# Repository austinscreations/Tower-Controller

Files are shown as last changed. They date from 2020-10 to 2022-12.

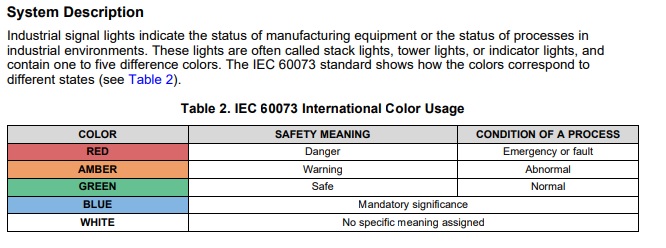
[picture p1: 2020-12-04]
tower light clasification.jpg

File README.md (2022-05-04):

# Tower Controller
# formerly mini-notification-tower

I've recently found good sellers for lower cost industrial towers, while I'll still 3d print my own 180 degree tower light and share files should someone want to build one, I've now designed a semi-universal controller for controlling analog 12-24v tower lights

New code can be found here: [Github](https://github.com/austinscreations/OXRS-AC-TowerController-ESP8266-FW) <br>
Load up a bin file in wifi or ethernet mode and provision the device using the admin UI: [Github](https://github.com/OXRS-IO/OXRS-IO-AdminUI-WEB-APP) <br>
Compatable with the (http://oxrs.io) system

As someone who has a home office and a workshop in the garage I wanted an easy way to have notifications whereever I am.
traditional 5 layer led notification lights are large and pricey.
I set out to make a smaller alternative solution. with 3d printing I made a 180 degree light, with the help of a 3d printed mold I was able to use epoxy resin and tints to create the lenses.

-

Red - flashing - immediate issue (such as a fire alarm or CO alarm)

Red - machine error (cnc or 3d printer)

Yellow - flashing - machine error / require attention (such as a 3d printer filament sensor or 3d print ends)

Yellow - equipement On - temperature related (3d printer active (hot end or heat bed) or soldering iron on)

Green - equipment on but idle (say 3d printer or soldering iron is on but not running a job

Blue - notifications (with the help of an I2C lcd I'm able to show messages

White - tied to my doorbell (one to my office door and front house door)

-

Version 1 used 5mm leds in a 3d printed insert - mosfets controlelr wired to 5v and arduino nano. the arduino nano was linked to an rf433 reciever for the doorbell.

Version 2 will include a PCB for a Wemos d1 mini and SMD leds, and I want to try to make a 360 degree model as well.
          
RF433 will be offloaded to a esp-01 to build a seprate gateway for my home assitant installation.

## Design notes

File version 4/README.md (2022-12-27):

this latest version include builtin ethernet support, POE support and runs on esp32

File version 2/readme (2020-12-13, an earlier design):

Version 2 

This version has the tower assembly using 5730 LEd's for lighting and a spot on the pcb for a wemos D1 mini.

***this version is larger than the v1 so taht both the 180 degree and 360 degree assebbilies can be the same size.***

Requires 12v power to run - diode proetcting 5v regualtor when programming via usb

will be updated as I create the PCB files, code and 3d housings will be made and adjusted once I order parts for assembly and testing.

2020-12-12
updated control board pcb in version 2 stacking edition
added intial 3d model photo of teh 3d printable model that will be used to assemble the lights

2020-12-04
added photos of the pcb designs of each version
added cost breakdown in main version 22 folder for each version. doesn't include 3d printed parts / power supply - using ebay canada as source

2020-12-03:
Created new files. there are different assemblies. 

180 version = has a single led panel with wemos d1 mini - giving ~180 degree ilumination

360 stacking = used a control board and led boards - using brass stand offs to conenct each baord. there are solder jumpers which are to be used to route the signal
for the ws2811s chip that controls the led mosfets. the depending on led color you need 82 ohm or 39 ohm 2010 1 watt resistors (text on pcb). 
each baord will allow you to program 3 segment animations on the led baord. 3d printed parts with 45 degree angles nad chrome paint can be used to redirect light.

360 version = uses 4 straight led panels to connect to a control board via 90 degree headers. uses ws2811s chip to control LED mosfets

Boards are currently untested and don't have 3d assembly files, working on multiple projects and home to do a mass ebay order to fill parts on these projects to keep my costs down.

Hope to expore the option of a POE powered and ethernet controlled tower

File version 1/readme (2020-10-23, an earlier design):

Readme for version 1

This version was created as I was testing a concept. I had intended to add an esp-01 to the arduino nano.
I wasn't able to have reliable communication through the esp-01 so version 2 will use a wemos d1 mini at it's core.

As this was a test for me and only uses an RF433mhz reciever to control the white led I wont be posting any code.

version 1 was hand soldered and 5mm led sat within a 3d printed insert. The lenses were made with a 3d printed mold filed with epoxy resin 
i used cheap dollar store resin as a test and didn't want to use my high quality stuff. and used resin tint for the colors.

The LEDS match the lens color - I found this gives the best results as using the white leds on the color produced a washed out color.

normal state of the lcd is to state time and temperature.

COMPUTER ASSEMBLY - 
holder - this was a holder i made that slides over my dual monitor mount post, it has a sleep and reset button along with lcd display spot.

sleep was used for when i'd go to bed as the arduino nano has control over the door bell sound it will play the sound every so often until i wake up and reset it.
   good for me as I'm partly deaf. it would also turn off the screen so that my room would be dark for sleeping
reset is used to reset the screen notification and intern reset a color on the tower if needed.

led panel is the panel used to insert 5mm leds and solder them together with resisters.

tower light cover is the back cover for the assembly, i glued mine in place, passed etehrnet cable thru the hole for the led wiring

tower light is the main tower assembly.

LENS - 

lens mold is parts a and b, they were alligned and hot glue at the seam. mann mold release 200 was used to prevent the resin from sticking.

lens shaper - i would allow the lens to mostly cure and still be flexible (warning teh resin wil lstill be warm in this state - i'd remove it from teh mold and place it within the shaper
this ensured that the lens was easy to remove from the mold and any moving it did coming out of teh mold gave it a chance to cure in the correct shape. found this gave me the best results
and with the use of 5 minute epoxy gave me chance to make lenses really quickly.

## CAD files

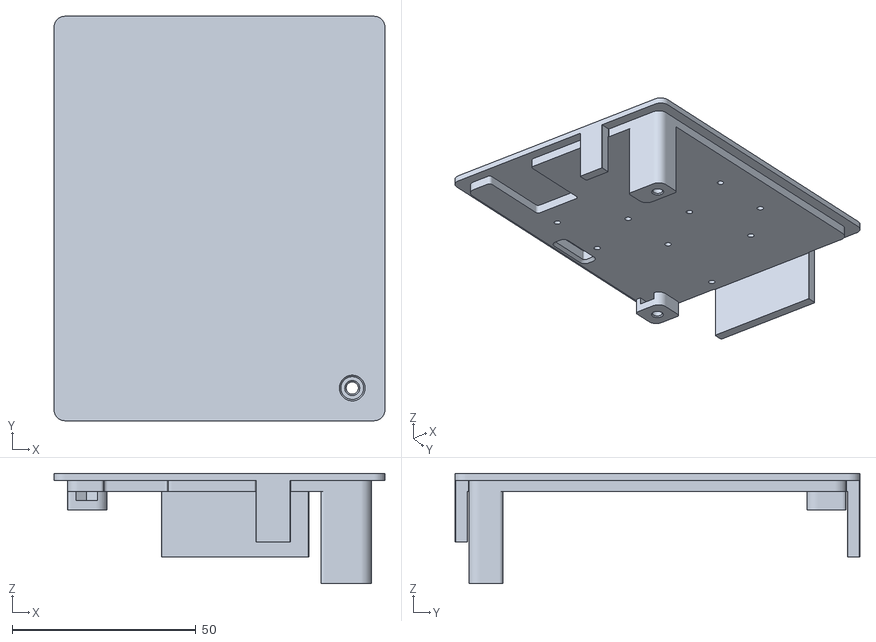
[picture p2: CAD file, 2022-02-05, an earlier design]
version 3/3d printable case/main lid.stl
90.0 x 110.0 x 30.0

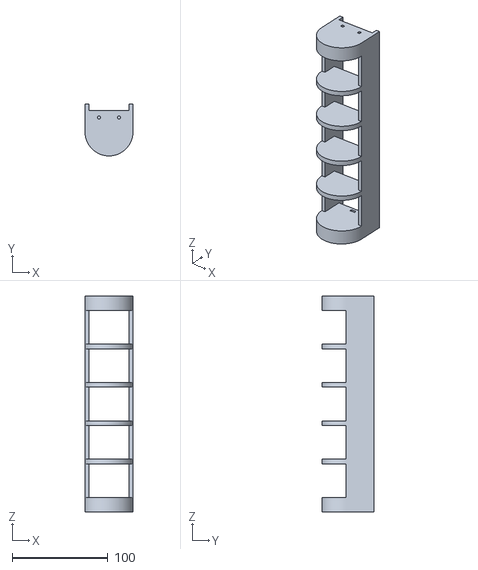
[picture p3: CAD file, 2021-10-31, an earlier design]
version 3/CAD/main body.stl
50.0 x 54.0 x 225.0

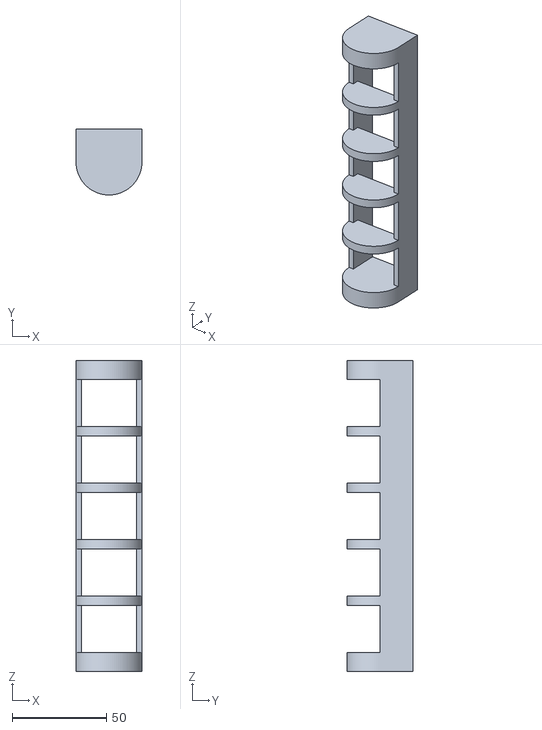
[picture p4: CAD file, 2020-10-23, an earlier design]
version 1/computer assembly/computer tower light.stl
35.0 x 35.0 x 165.0

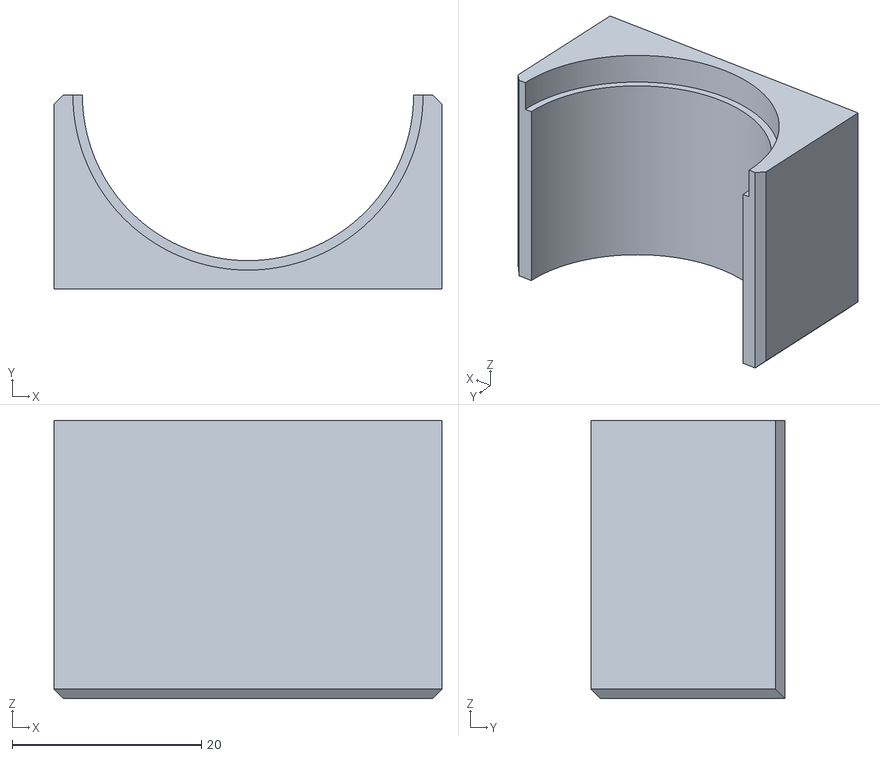
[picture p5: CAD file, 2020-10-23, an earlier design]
version 1/lens/lens mold 2.stl
41.0 x 20.5 x 29.4

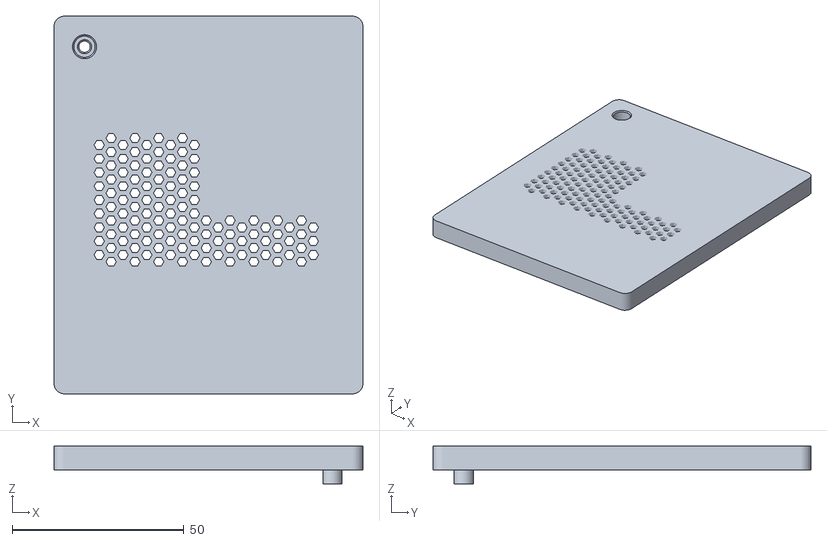
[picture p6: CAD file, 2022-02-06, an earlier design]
version 3/3d printable case/sensor lid.stl
90.0 x 110.0 x 11.0

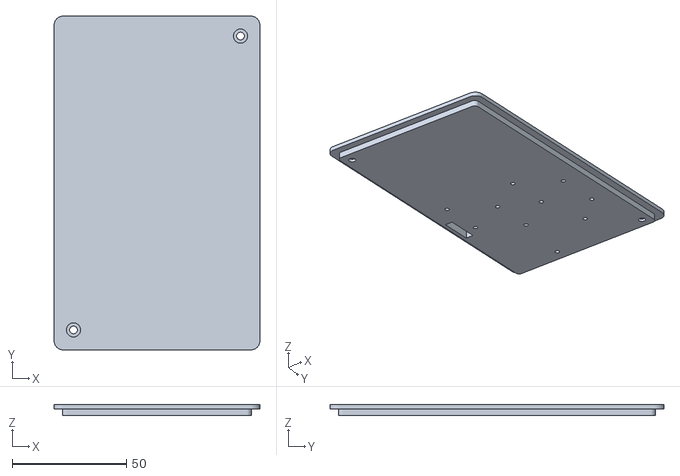
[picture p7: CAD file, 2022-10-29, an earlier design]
version 3/3d printable case/wall mount case/wall case lid v1.stl
90.0 x 146.0 x 5.00

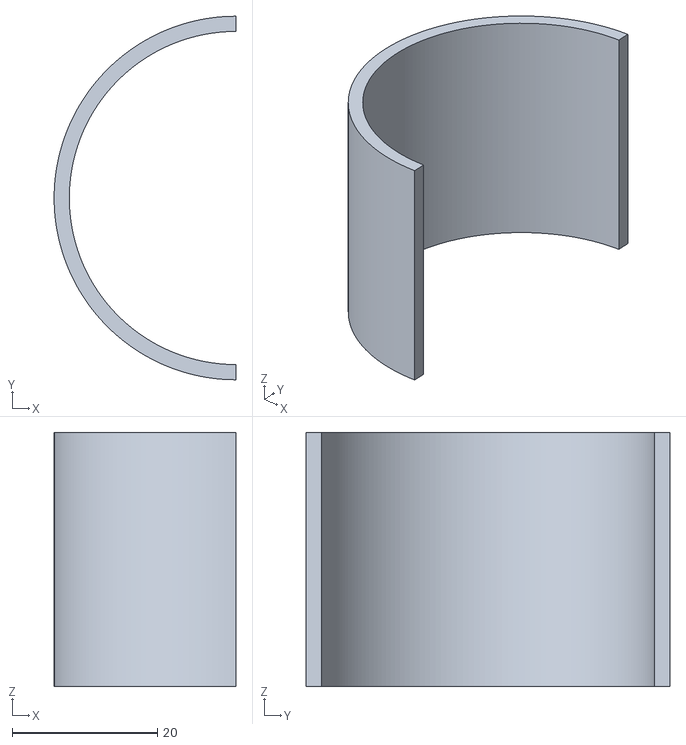
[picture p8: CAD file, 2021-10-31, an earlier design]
version 3/CAD/lens.stl
25.0 x 50.1 x 35.0

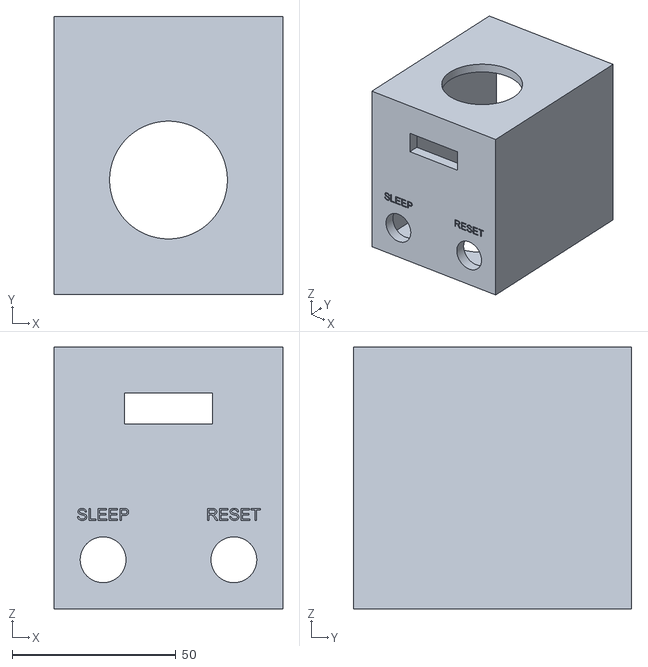
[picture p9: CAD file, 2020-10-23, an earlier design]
version 1/computer assembly/computer holder.stl
70.0 x 85.0 x 80.0

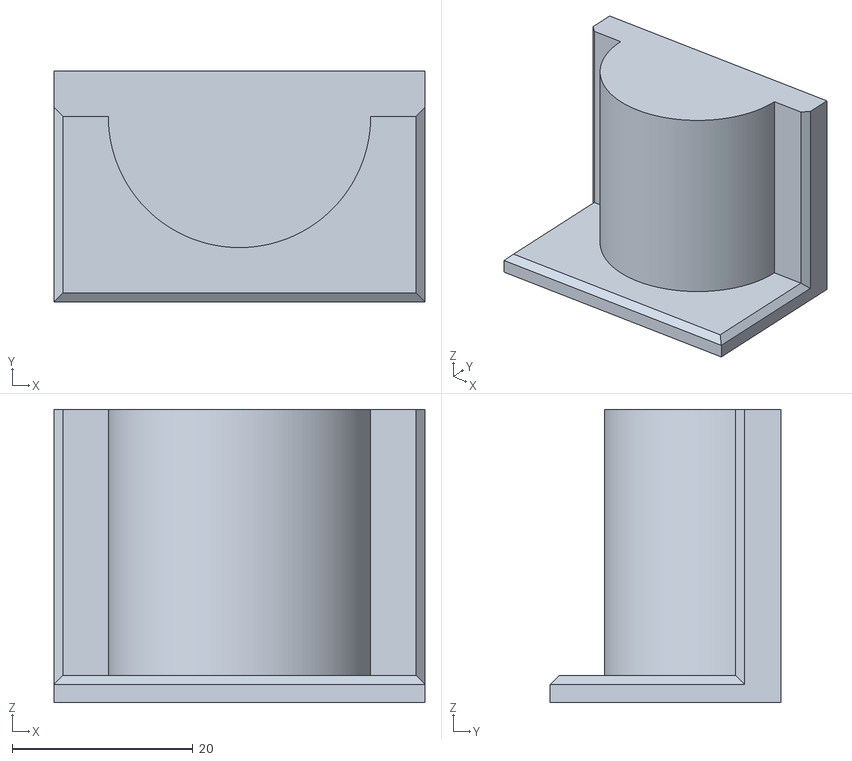
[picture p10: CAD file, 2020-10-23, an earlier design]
version 1/lens/lens mold 1.stl
41.0 x 25.5 x 32.4

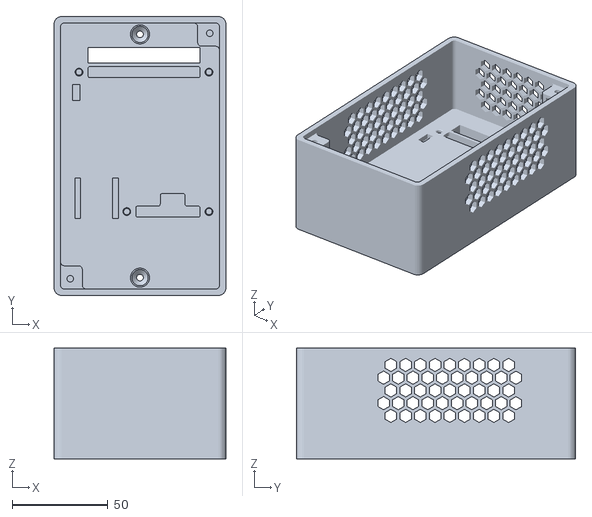
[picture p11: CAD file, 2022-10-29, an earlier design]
version 3/3d printable case/wall mount case/wall case v1.stl
90.0 x 146.0 x 58.0

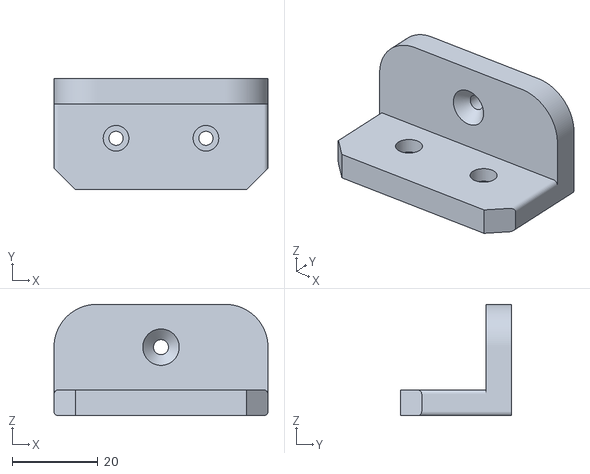
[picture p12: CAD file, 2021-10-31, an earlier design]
version 3/CAD/wall mount.stl
50.0 x 26.0 x 26.0

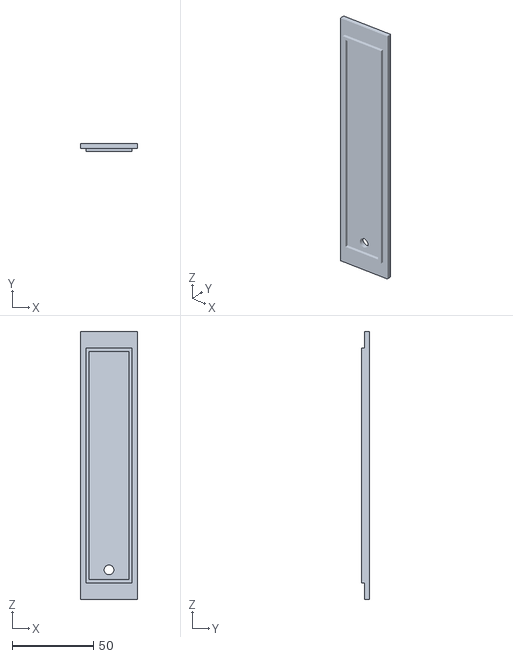
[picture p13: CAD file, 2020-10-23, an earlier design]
version 1/computer assembly/computer tower light cover.stl
35.0 x 5.00 x 165.0

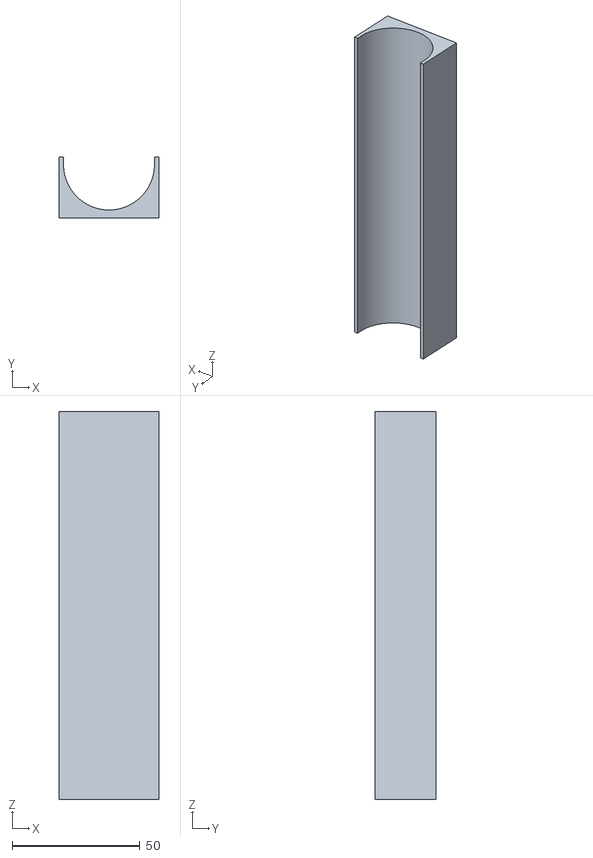
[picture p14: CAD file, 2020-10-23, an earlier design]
version 1/lens/Resin lens shaper.stl
39.0 x 24.0 x 152.0

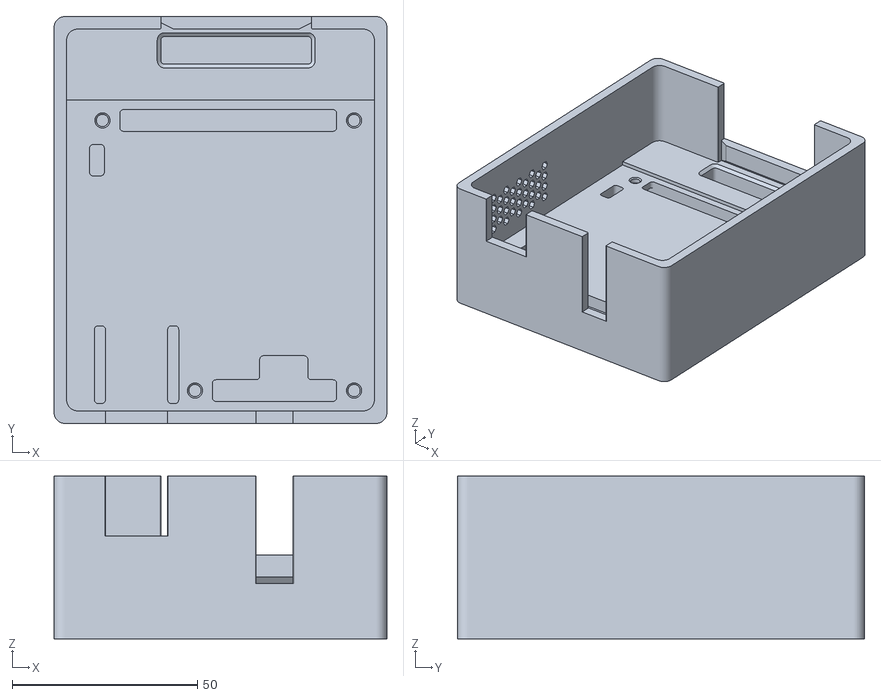
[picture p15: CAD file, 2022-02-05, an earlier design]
version 3/3d printable case/case.stl
90.0 x 110.0 x 44.0

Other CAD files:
version 3/CAD/mold rest.stl
version 1/computer assembly/computer led panel.stl
version 3/CAD/back panel.stl
version 3/CAD/tower light.step
version 3/CAD/mold a.stl
version 3/CAD/mold b.stl

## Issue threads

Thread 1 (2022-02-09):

ScreenMode is missing in 1.0.2

aspork42, 2022-02-09:
References to ScreenMode no longer appear in 1.0.2 (as compared with 0.9)

austinscreations, 2022-02-09:
updated nodered flow and screenmode code moved to OXRS sensor library

Closed 2022-02-09.

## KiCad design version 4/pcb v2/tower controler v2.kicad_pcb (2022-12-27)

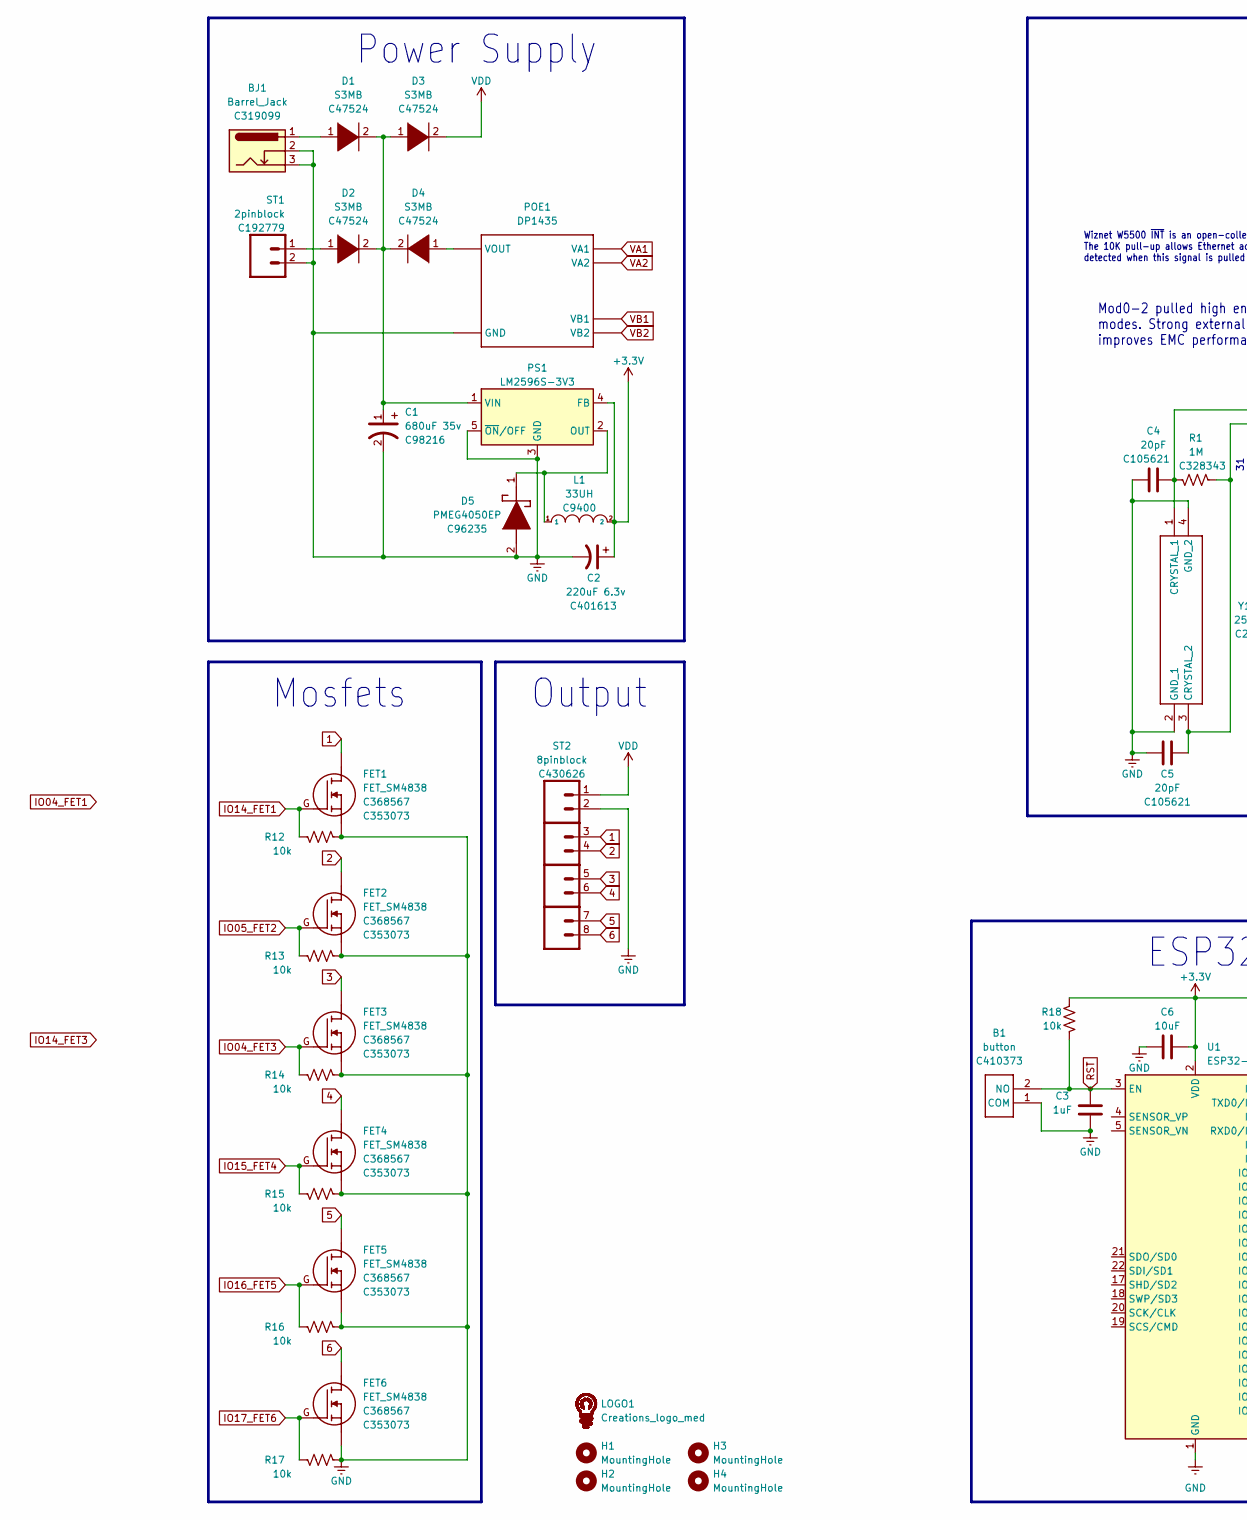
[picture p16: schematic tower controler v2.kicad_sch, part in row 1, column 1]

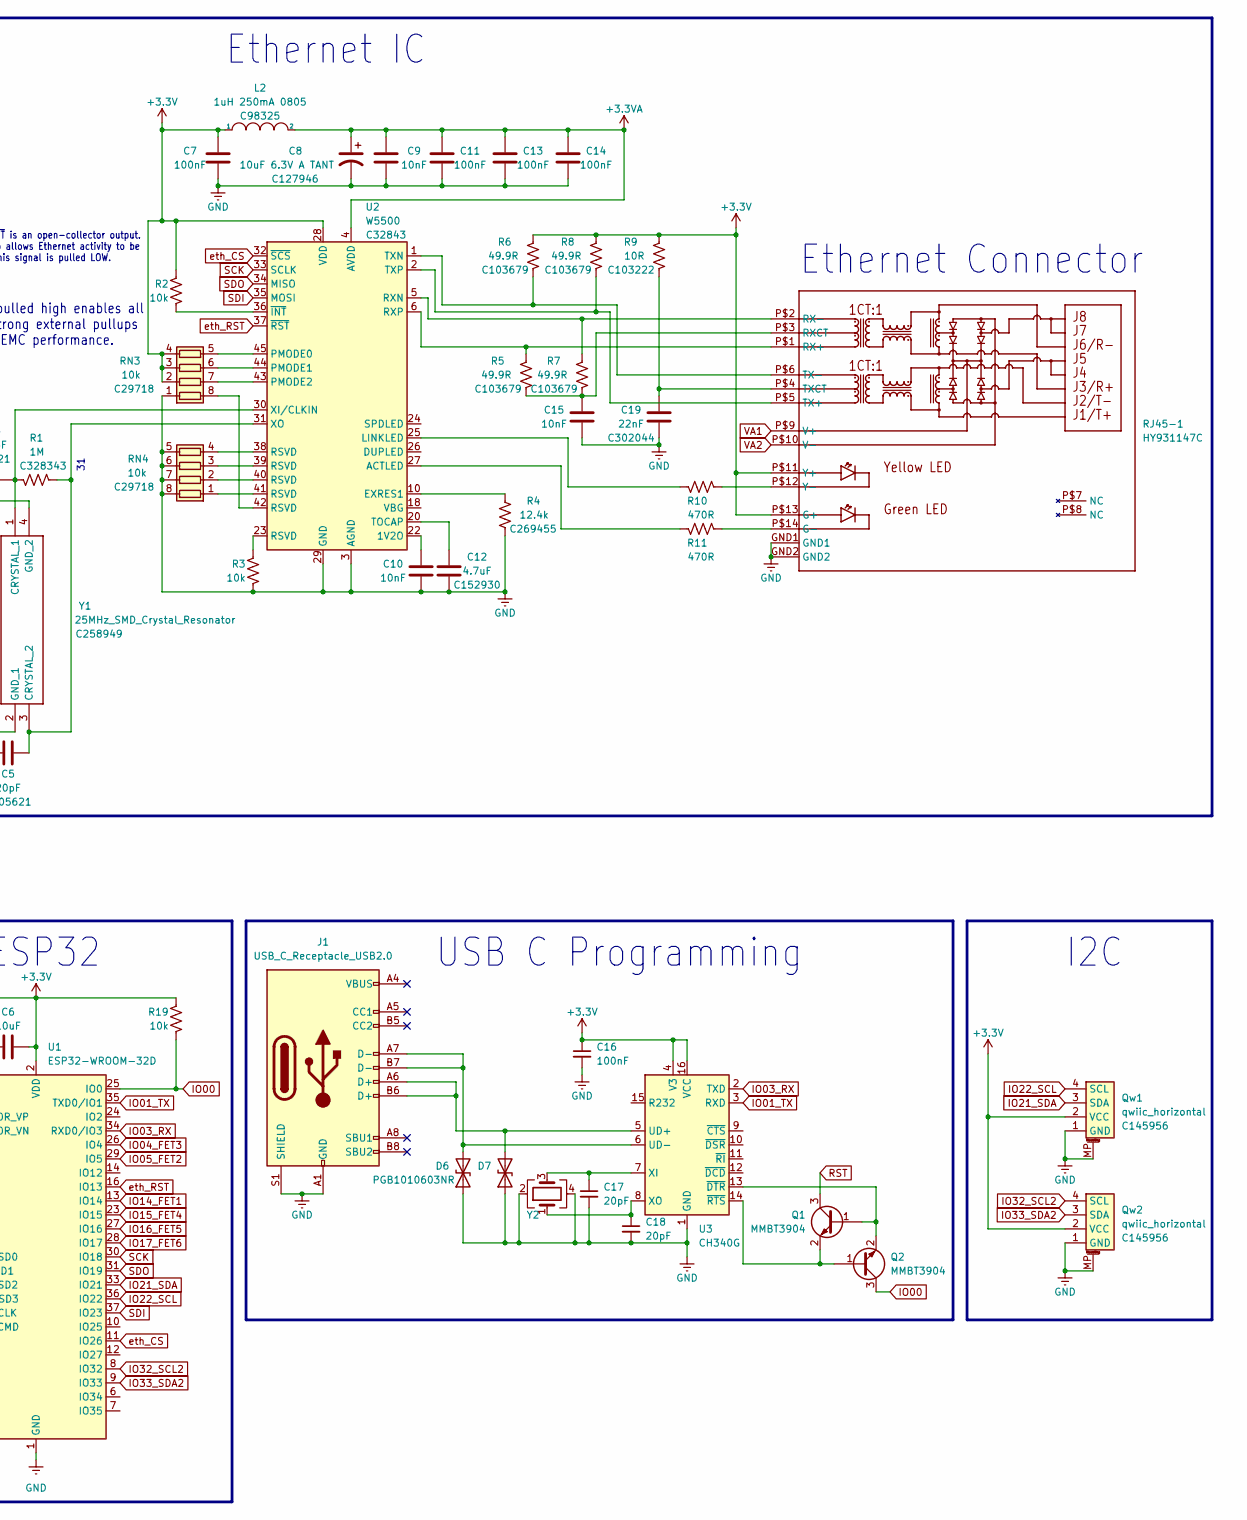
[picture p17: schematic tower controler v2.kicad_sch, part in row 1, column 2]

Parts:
B1: button; part # C410373
BJ1: Barrel_Jack; Barrel Jack; part # C319099
C1: 680uF 35v; large capacitor 12.5d 13.5h; part # C98216
C2: 220uF 6.3v; CP_Elec_8x6.2; part # C401613
C3: 1uF; C_0603_1608Metric
C4, C5: 20pF; C_0603_1608Metric; part # C105621
C6: 10uF; C_0603_1608Metric
C7, C11, C13, C14, C16: 100nF; C_0603_1608Metric
C8: 10uF 6.3V A TANT; CP_EIA-3216-18_Kemet-A; part # C127946
C9, C10, C15: 10nF; C_0603_1608Metric
C12: 4.7uF; C_0603_1608Metric; part # C152930
C17, C18: 20pF; C_0603_1608Metric
C19: 22nF; C_0603_1608Metric; part # C302044
D1, D2, D3, D4: S3MB; D_SMB; part # C47524
D5: PMEG4050EP; PMEG3050EP; part # C96235
D6, D7: PGB1010603NR; D_0603_1608Metric
FET1, FET2, FET3, FET4, FET5, FET6: FET_SM4838; FET SM4838; part # C368567
H1, H2, H3, H4: MountingHole; MountingHole_3.2mm_M3
J1: USB_C_Receptacle_USB2.0; USB_C_Receptacle_HRO_TYPE-C-31-M-12
L1: 33UH; 12x12x8 inductor; part # C9400
L2: 1uH 250mA 0805; L_0805_2012Metric; part # C98325
LOGO1: Creations_logo_med; Creations logo med
POE1: DP1435
PS1: LM2596S-3V3; LM2596S
Q1, Q2: MMBT3904; SOT-23
Qw1, Qw2: qwiic_horizontal; qwiic horizontal; part # C145956
R1: 1M; R_0603_1608Metric; part # C328343
R2, R3, R12, R13, R14, R15, R16, R17, R18, R19: 10k; R_0603_1608Metric
R4: 12.4k; R_0603_1608Metric; part # C269455
R5, R6, R7, R8: 49.9R; R_0603_1608Metric; part # C103679
R9: 10R; R_0603_1608Metric; part # C103222
R10, R11: 470R; R_0603_1608Metric
RJ45-1: HY931147C
RN3, RN4: 10k; R_Array_Convex_4x0603; part # C29718
ST1: 2pinblock; part # C192779
ST2: 8pinblock; part # C430626
U1: ESP32-WROOM-32D; ESP32-WROOM-32
U2: W5500; LQFP-48_7x7mm_P0.5mm; part # C32843
U3: CH340G; SOIC-16_3.9x9.9mm_P1.27mm
Y1: 25MHz_SMD_Crystal_Resonator; part # C258949
Y2: Crystal_GND23; Crystal_SMD_3225-4Pin_3.2x2.5mm

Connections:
1: FET1.D, ST2.3
2: FET2.D, ST2.4
3: FET3.D, ST2.5
4: FET4.D, ST2.6
5: FET5.D, ST2.7
6: FET6.D, ST2.8
+3.3VA: C8.1, C9.2, C11.2, C13.2, C14.2, L2.2, U2.4 (AVDD), U2.8 (AVDD), U2.11 (AVDD), U2.15 (AVDD), U2.17 (AVDD), U2.21 (AVDD)
+3V3: C2.1, C6.2, C7.2, C16.1, L1.2, L2.1, PS1.4 (FB), Qw1.2 (VCC), Qw2.2 (VCC), R2.2, R6.2, R8.2, R9.2, R18.2, R19.2, RJ45-1.P$11 (Y+), RJ45-1.P$13 (G+), RN3.2 (R2.1), RN3.3 (R3.1), RN3.4 (R4.1), U1.2 (VDD), U2.28 (VDD), U3.4 (V3), U3.16 (VCC)
GNDREF: B1.1 (COM), BJ1.2, BJ1.3, C1.2, C2.2, C3.1, C4.1, C5.1, C6.1, C7.1, C8.2, C9.1, C10.1, C11.1, C12.1, C13.1, C14.1, C15.1, C16.2, C17.2, C18.2, C19.1, D5.2 (A), D6.1 (A1), D7.1 (A1), FET1.S, FET2.S, FET3.S, FET4.S, FET5.S, FET6.S, J1.A1 (GND), J1.A12 (GND), J1.B1 (GND), J1.B12 (GND), J1.S1 (SHIELD), POE1.GND, PS1.3 (GND), PS1.5 (~ON/OFF), Qw1.1 (GND), Qw1.MP, Qw2.1 (GND), Qw2.MP, R3.1, R4.1, R12.1, R13.1, R14.1, R15.1, R16.1, R17.1, RJ45-1.GND1, RJ45-1.GND2, RN3.1 (R1.1), RN4.5 (R4.2), RN4.6 (R3.2), RN4.7 (R2.2), RN4.8 (R1.2), ST1.2, ST2.2, U1.1 (GND), U1.15 (GND), U1.38 (GND), U1.39 (GND), U2.3 (AGND), U2.9 (AGND), U2.14 (AGND), U2.16 (AGND), U2.19 (AGND), U2.29 (GND), U2.48 (AGND), U3.1 (GND), Y1.2 (GND_1), Y1.4 (GND_2), Y2.2, Y2.4
IO00: Q2.3 (C), R19.1, U1.25 (IO0)
IO01_TX: U1.35 (TXD0/IO1), U3.3 (RXD)
IO03_RX: U1.34 (RXD0/IO3), U3.2 (TXD)
IO04_FET3: FET3.G, R14.2, U1.26 (IO4)
IO05_FET2: FET2.G, R13.2, U1.29 (IO5)
IO14_FET1: FET1.G, R12.2, U1.13 (IO14)
IO15_FET4: FET4.G, R15.2, U1.23 (IO15)
IO16_FET5: FET5.G, R16.2, U1.27 (IO16)
IO17_FET6: FET6.G, R17.2, U1.28 (IO17)
IO21_SDA: Qw1.3 (SDA), U1.33 (IO21)
IO22_SCL: Qw1.4 (SCL), U1.36 (IO22)
IO32_SCL2: Qw2.4 (SCL), U1.8 (IO32)
IO33_SDA2: Qw2.3 (SDA), U1.9 (IO33)
unnamed: BJ1.1, D1.1 (K)
unnamed: C1.1, D1.2 (A), D2.2 (A), D3.1 (K), D4.2 (A), PS1.1 (VIN)
unnamed: C4.2, R1.1, U2.30 (XI/CLKIN), Y1.1 (CRYSTAL_1)
unnamed: C5.2, R1.2, U2.31 (XO), Y1.3 (CRYSTAL_2)
unnamed: C10.2, U2.22 (1V2O)
unnamed: C12.2, U2.20 (TOCAP)
unnamed: C15.2, R5.1, R7.1, RJ45-1.P$3 (RXCT)
unnamed: C17.1, U3.7 (XI), Y2.3
unnamed: C18.1, U3.8 (XO), Y2.1
unnamed: C19.2, R9.1, RJ45-1.P$4 (TXCT)
unnamed: D2.1 (K), ST1.1
unnamed: D4.1 (K), POE1.VOUT
unnamed: D5.1 (K), L1.1, PS1.2 (OUT)
unnamed: D6.2 (A2), J1.A7 (D-), J1.B7 (D-), U3.6 (UD-)
unnamed: D7.2 (A2), J1.A6 (D+), J1.B6 (D+), U3.5 (UD+)
unnamed: Q1.1 (B), Q2.2 (E), U3.13 (~DTR)
unnamed: Q1.2 (E), Q2.1 (B), U3.14 (~RTS)
unnamed: R2.1, U2.36 (~INT)
unnamed: R3.2, U2.23 (RSVD)
unnamed: R4.2, U2.10 (EXRES1)
unnamed: R5.2, RJ45-1.P$1 (RX+), U2.6 (RXP)
unnamed: R6.1, RJ45-1.P$6 (TX-), U2.1 (TXN)
unnamed: R7.2, RJ45-1.P$2 (RX-), U2.5 (RXN)
unnamed: R8.1, RJ45-1.P$5 (TX+), U2.2 (TXP)
unnamed: R10.1, RJ45-1.P$12 (Y-)
unnamed: R10.2, U2.25 (LINKLED)
unnamed: R11.1, RJ45-1.P$14 (G-)
unnamed: R11.2, U2.27 (ACTLED)
unnamed: RN3.5 (R4.2), U2.45 (PMODE0)
unnamed: RN3.6 (R3.2), U2.44 (PMODE1)
unnamed: RN3.7 (R2.2), U2.43 (PMODE2)
unnamed: RN3.8 (R1.2), U2.42 (RSVD)
unnamed: RN4.1 (R1.1), U2.41 (RSVD)
unnamed: RN4.2 (R2.1), U2.40 (RSVD)
unnamed: RN4.3 (R3.1), U2.39 (RSVD)
unnamed: RN4.4 (R4.1), U2.38 (RSVD)
RST: B1.2 (NO), C3.2, Q1.3 (C), R18.1, U1.3 (EN)
SCK: U1.30 (IO18), U2.33 (SCLK)
SDI: U1.37 (IO23), U2.35 (MOSI)
SDO: U1.31 (IO19), U2.34 (MISO)
VA1: POE1.VA1, RJ45-1.P$9 (V+)
VA2: POE1.VA2, RJ45-1.P$10 (V-)
VB1: POE1.VB1
VB2: POE1.VB2
VDD: D3.2 (A), ST2.1
eth_CS: U1.11 (IO26), U2.32 (~SCS)
eth_RST: U1.16 (IO13), U2.37 (~RST)

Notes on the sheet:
Ethernet Connector
Ethernet IC
USB C Programming
ESP32
Power Supply
Mod0-2 pulled high enables all modes. Strong external pullups improves EMC performance.
Output
Mosfets
I2C
Wiznet W5500 ~{INT} is an open-collector output. The 10K pull-up allows Ethernet activity to be detected when this signal is pulled LOW.

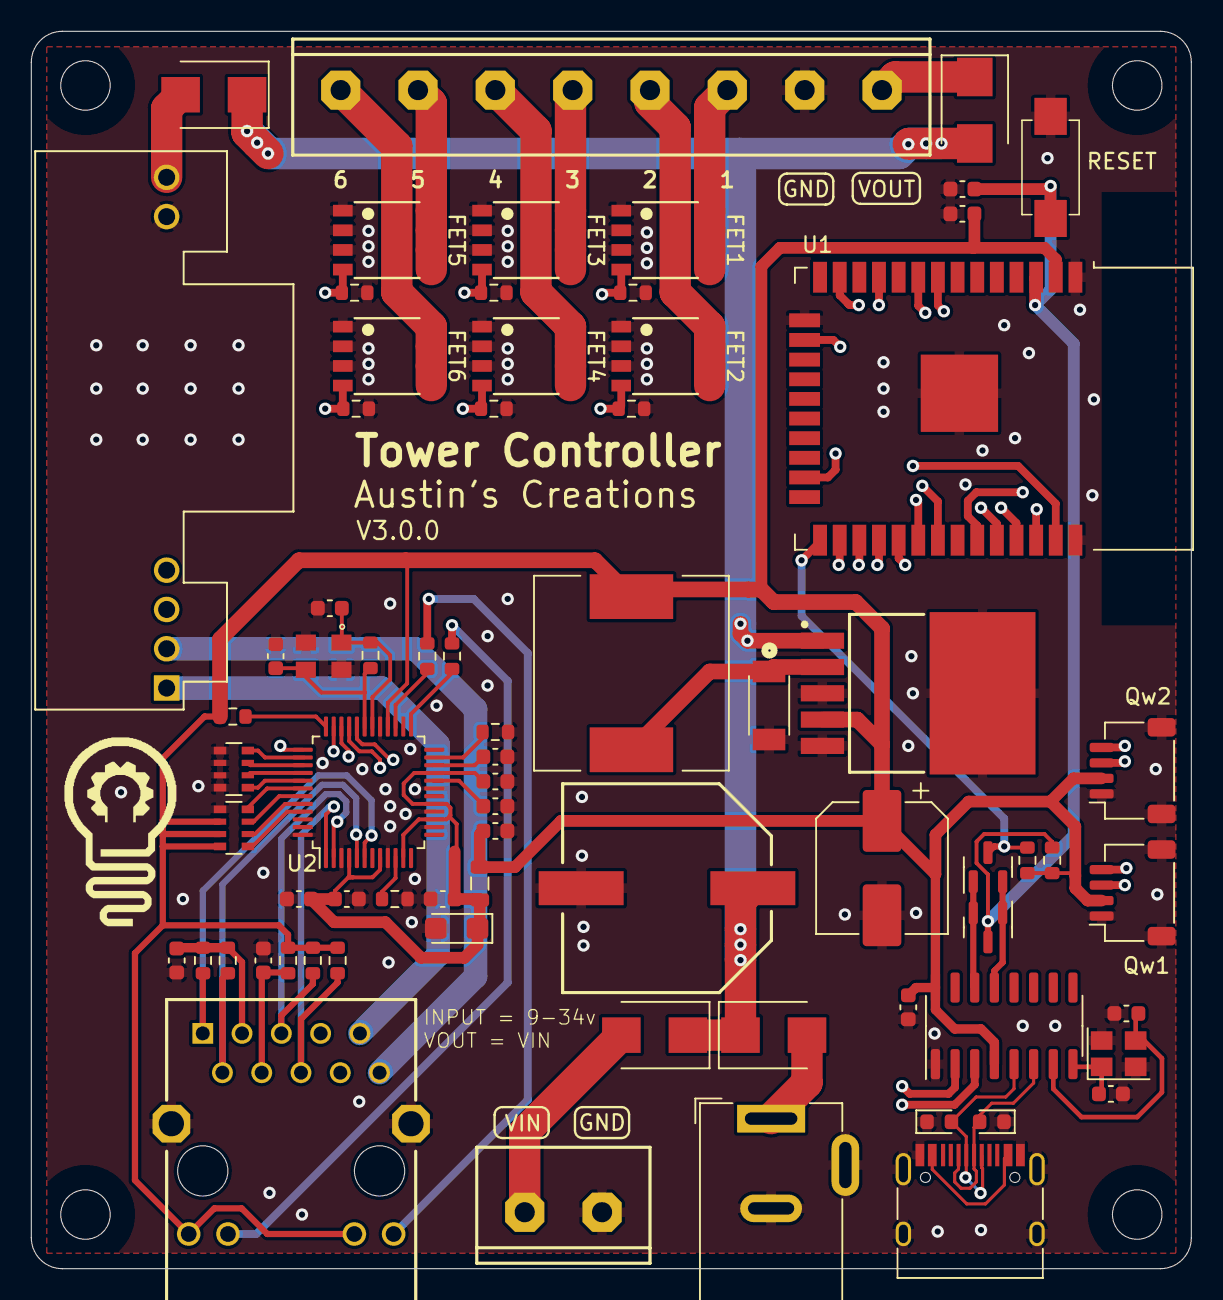
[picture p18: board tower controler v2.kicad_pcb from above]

Board: 4 copper layers, 75.0 x 80.0 mm, 77 parts (0 on the bottom side), 67 nets.

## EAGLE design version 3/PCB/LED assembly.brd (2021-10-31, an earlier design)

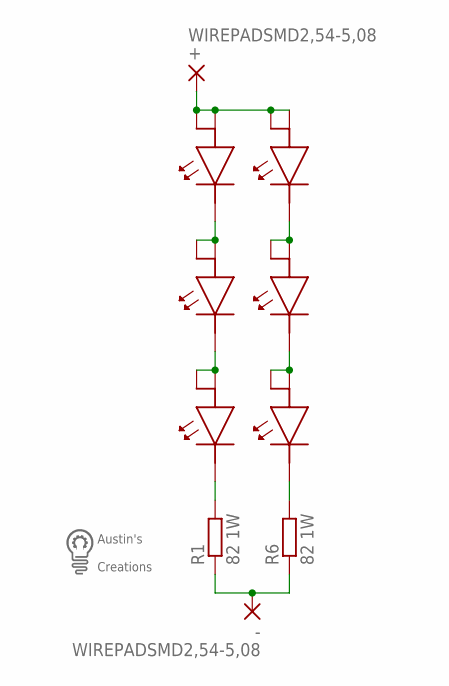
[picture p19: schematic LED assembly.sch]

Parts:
+: WIREPADSMD2,54-5,08; SMD2,54-5,08
-: WIREPADSMD2,54-5,08; SMD2,54-5,08
R1, R6: 82 1W; R2010
U$1: LOGOMED
U$6, U$7, U$8, U$23, U$24, U$25: 5730LED

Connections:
N: U$6.P$2, U$7.P$1, U$7.P$3
unnamed: -.1, R1.1, R6.1
unnamed: U$7.P$2, U$8.P$1, U$8.P$3
unnamed: R1.2, U$8.P$2
unnamed: U$23.P$2, U$24.P$1, U$24.P$3
unnamed: U$24.P$2, U$25.P$1, U$25.P$3
unnamed: R6.2, U$25.P$2
VIN: +.1, U$6.P$1, U$6.P$3, U$23.P$1, U$23.P$3

Board: 2 copper layers, 11 parts (0 on the bottom side), 8 nets, no tracks yet.

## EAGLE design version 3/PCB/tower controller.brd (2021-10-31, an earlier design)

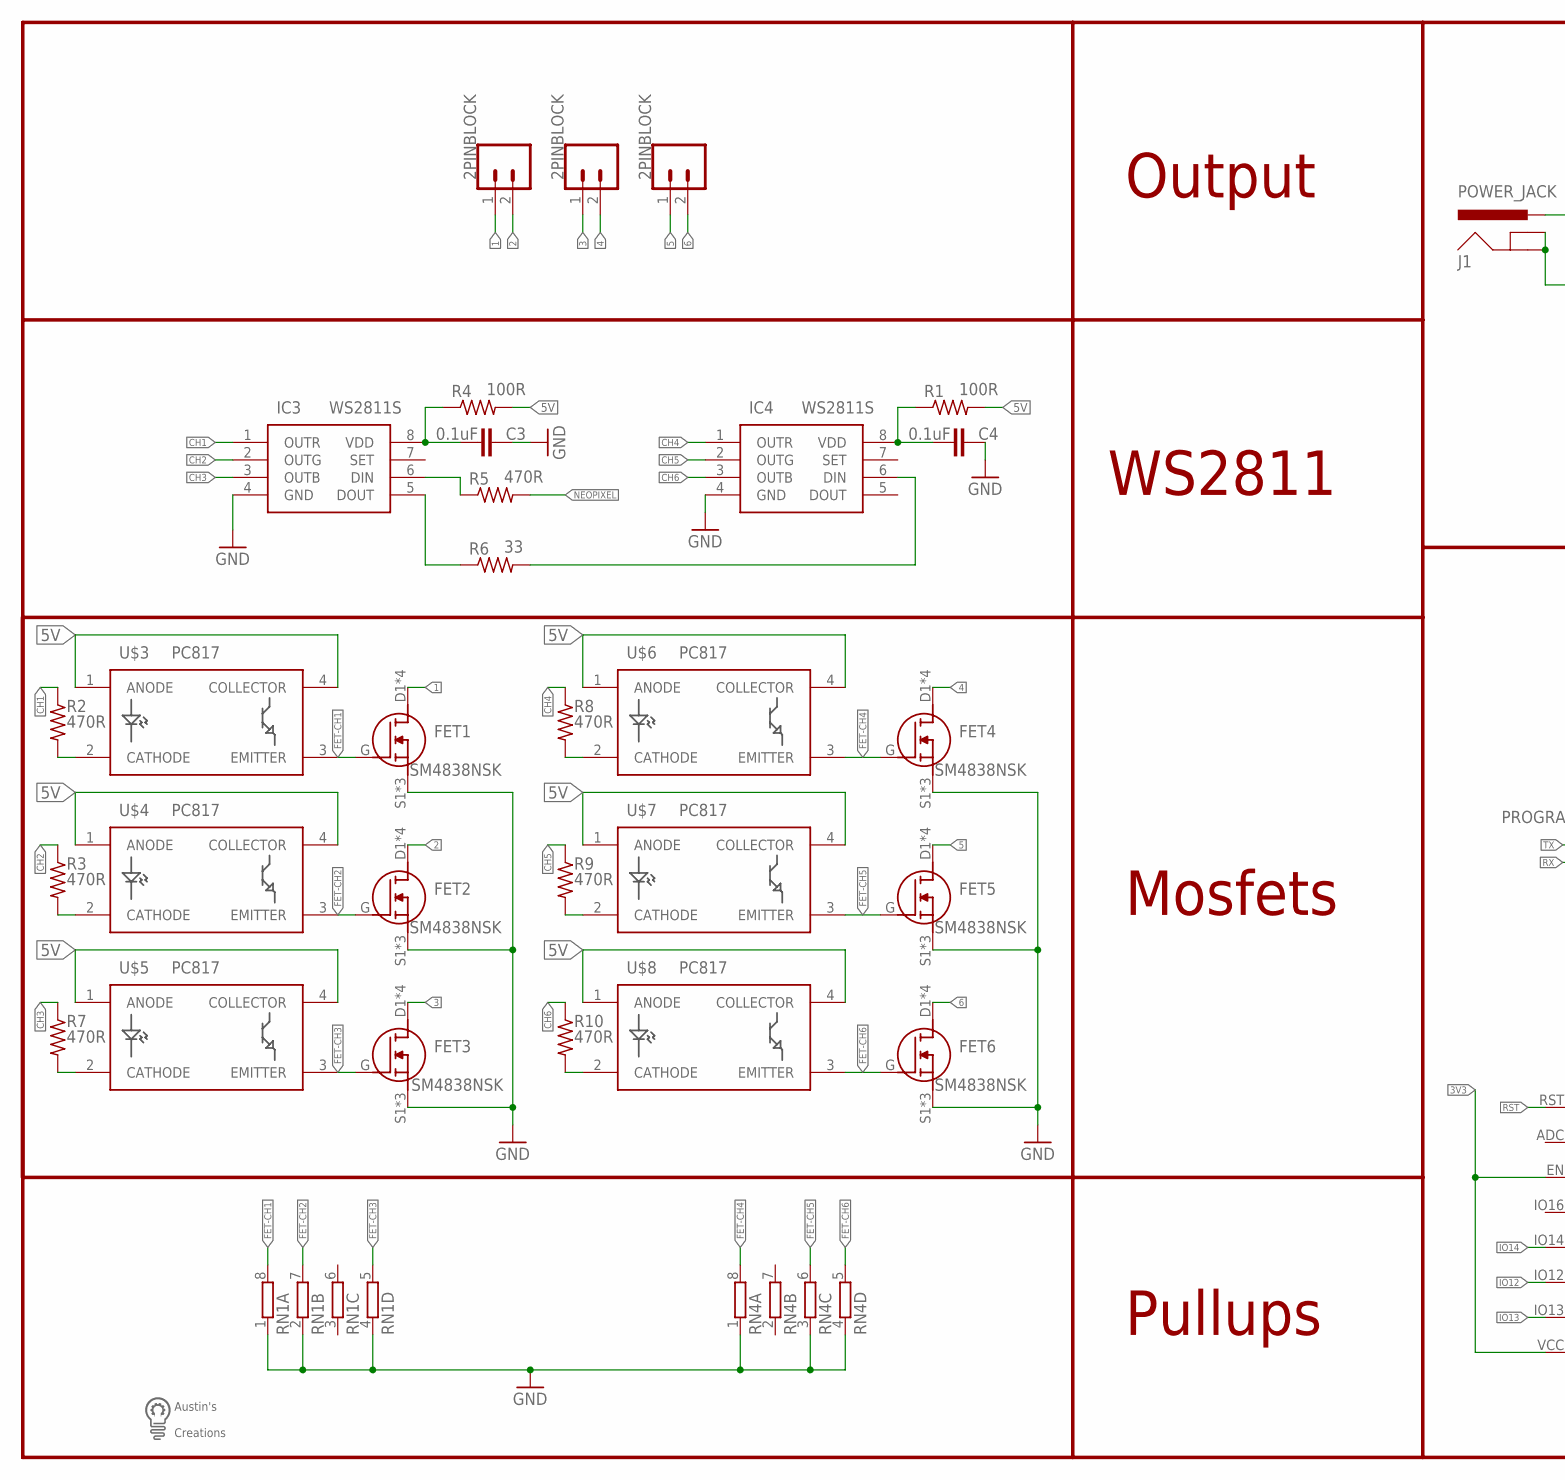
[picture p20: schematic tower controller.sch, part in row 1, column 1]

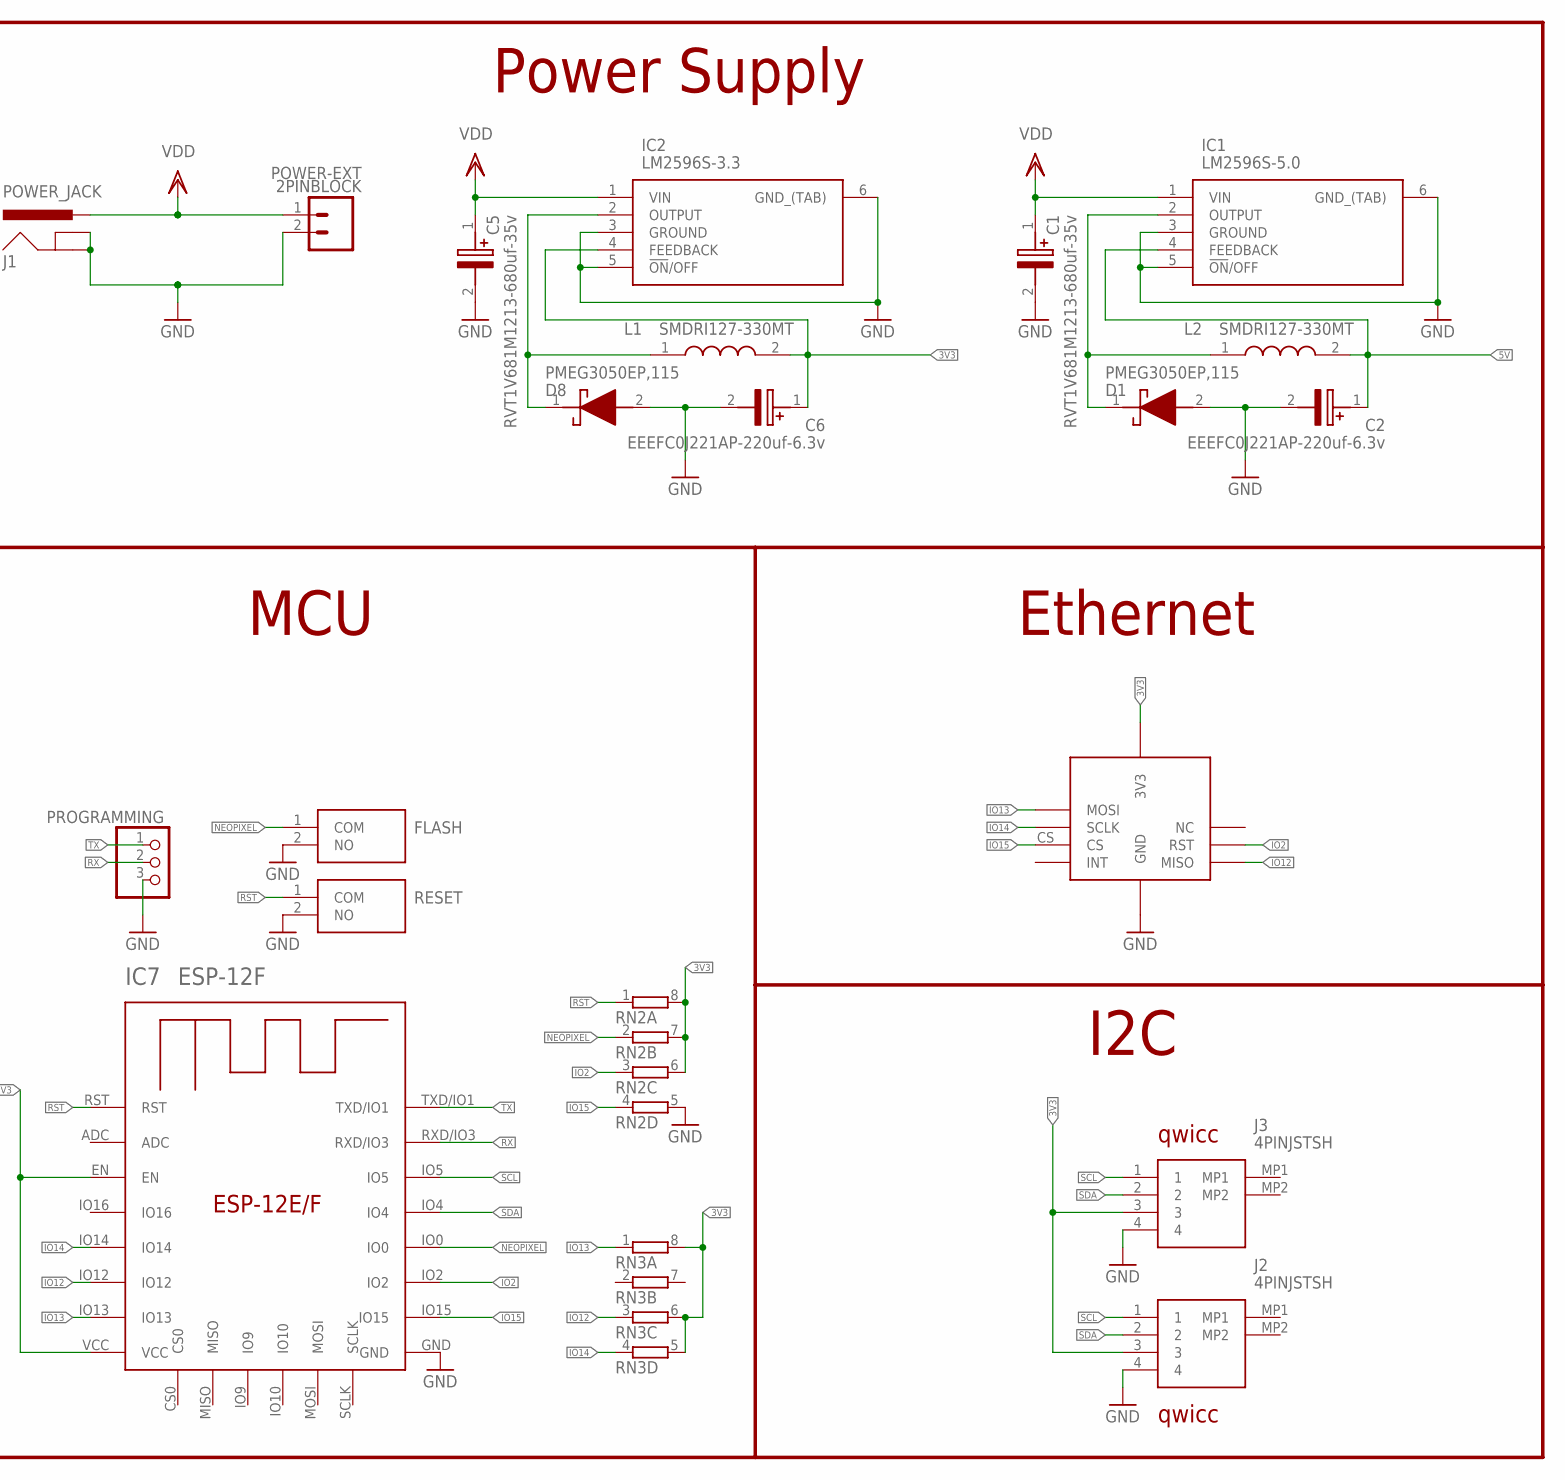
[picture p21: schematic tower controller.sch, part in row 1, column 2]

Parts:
C1, C5: RVT1V681M1213-680uf-35v; CAPAE1350X1400N
C2, C6: EEEFC0J221AP-220uf-6.3v; CAPAE830X650N
C3, C4: 0.1uF; C0603
D1, D8: PMEG3050EP,115; PMEG3050EP115
FET1, FET2, FET3, FET4, FET5, FET6: SM4838NSK
FLASH: PTS636_SM25F_SMTR_LFS; PTS636SM25FSMTRLFS
GND, GND10, GND11: 2PINBLOCK; SCREWTERMINAL-5MM-2
IC1: LM2596S-5.0; TO170P1435X465-6N
IC2: LM2596S-3.3; TO170P1435X465-6N
IC3, IC4: WS2811S; SOIC127P600X175-8N
IC7: ESP-12F; ESP-12E
J1: POWER_JACK; POWER_JACK_PTH
J2, J3: 4PINJSTSH; 665104131822
L1, L2: SMDRI127-330MT; INDPM120120X800N
POWER-EXT: 2PINBLOCK; SCREWTERMINAL-5MM-2
PROGRAMMING: PINHD-1X3; 1X03
R1, R4: 100R; R0603
R2, R3, R5, R7, R8, R9, R10: 470R; R0603
R6: 33; R0603
RESET: PTS636_SM25F_SMTR_LFS; PTS636SM25FSMTRLFS
RN1, RN2, RN3, RN4: 4R-N0603-ARC; 0603-ARC
U$1: W5500MODULE
U$2: LOGOMED
U$3, U$4, U$5, U$6, U$7, U$8: PC817; SOP254P960X420-4N

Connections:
1: FET1.D1 (D), FET1.D2 (D), FET1.D3 (D), FET1.D4 (D), GND.1
2: FET2.D1 (D), FET2.D2 (D), FET2.D3 (D), FET2.D4 (D), GND.2
3: FET3.D1 (D), FET3.D2 (D), FET3.D3 (D), FET3.D4 (D), GND10.1
3V3: C6.1 (+), IC2.4 (FEEDBACK), IC7.EN, IC7.VCC, J2.3, J3.3, L1.2, RN2.6 (2), RN2.7 (2), RN2.8 (2), RN3.5 (2), RN3.6 (2), RN3.8 (2), U$1.3V3_1 (3V3), U$1.3V3_2 (3V3)
4: FET4.D1 (D), FET4.D2 (D), FET4.D3 (D), FET4.D4 (D), GND10.2
5: FET5.D1 (D), FET5.D2 (D), FET5.D3 (D), FET5.D4 (D), GND11.1
5V: C2.1 (+), IC1.4 (FEEDBACK), L2.2, R1.2, R4.2, U$3.1 (ANODE), U$3.4 (COLLECTOR), U$4.1 (ANODE), U$4.4 (COLLECTOR), U$5.1 (ANODE), U$5.4 (COLLECTOR), U$6.1 (ANODE), U$6.4 (COLLECTOR), U$7.1 (ANODE), U$7.4 (COLLECTOR), U$8.1 (ANODE), U$8.4 (COLLECTOR)
6: FET6.D1 (D), FET6.D2 (D), FET6.D3 (D), FET6.D4 (D), GND11.2
CH1: IC3.1 (OUTR), R2.1
CH2: IC3.2 (OUTG), R3.1
CH3: IC3.3 (OUTB), R7.1
CH4: IC4.1 (OUTR), R8.1
CH5: IC4.2 (OUTG), R9.1
CH6: IC4.3 (OUTB), R10.1
FET-CH1: FET1.G, RN1.8 (2), U$3.3 (EMITTER)
FET-CH2: FET2.G, RN1.7 (2), U$4.3 (EMITTER)
FET-CH3: FET3.G, RN1.5 (2), U$5.3 (EMITTER)
FET-CH4: FET4.G, RN4.8 (2), U$6.3 (EMITTER)
FET-CH5: FET5.G, RN4.6 (2), U$7.3 (EMITTER)
FET-CH6: FET6.G, RN4.5 (2), U$8.3 (EMITTER)
GND: C1.2 (-), C2.2 (-), C3.1, C4.1, C5.2 (-), C6.2 (-), D1.2 (A), D8.2 (A), FET1.S1 (S), FET1.S2 (S), FET1.S3 (S), FET2.S1 (S), FET2.S2 (S), FET2.S3 (S), FET3.S1 (S), FET3.S2 (S), FET3.S3 (S), FET4.S1 (S), FET4.S2 (S), FET4.S3 (S), FET5.S1 (S), FET5.S2 (S), FET5.S3 (S), FET6.S1 (S), FET6.S2 (S), FET6.S3 (S), FLASH.2 (NO), IC1.3 (GROUND), IC1.5 (!ON!/OFF), IC1.6 (GND_(TAB)), IC2.3 (GROUND), IC2.5 (!ON!/OFF), IC2.6 (GND_(TAB)), IC3.4 (GND), IC4.4 (GND), IC7.GND, J1.GND, J1.GNDBREAK, J2.4, J3.4, POWER-EXT.2, PROGRAMMING.3, RESET.2 (NO), RN1.1, RN1.2 (1), RN1.4 (1), RN2.5 (2), RN4.1, RN4.3 (1), RN4.4 (1), U$1.GND1 (GND), U$1.GND2 (GND), U$1.GND3 (GND)
IO2: IC7.IO2, RN2.3 (1), U$1.RST
IO12: IC7.IO12, RN3.3 (1), U$1.MISO
IO13: IC7.IO13, RN3.1, U$1.MOSI
IO14: IC7.IO14, RN3.4 (1), U$1.SCLK
IO15: IC7.IO15, RN2.4 (1), U$1.CS
unnamed: D1.1 (K), IC1.2 (OUTPUT), L2.1
unnamed: C4.2, IC4.8 (VDD), R1.1
unnamed: IC4.6 (DIN), R6.2
unnamed: C3.2, IC3.8 (VDD), R4.1
unnamed: IC3.6 (DIN), R5.1
unnamed: IC3.5 (DOUT), R6.1
unnamed: R3.2, U$4.2 (CATHODE)
unnamed: R2.2, U$3.2 (CATHODE)
unnamed: R7.2, U$5.2 (CATHODE)
unnamed: R8.2, U$6.2 (CATHODE)
unnamed: R9.2, U$7.2 (CATHODE)
unnamed: R10.2, U$8.2 (CATHODE)
unnamed: D8.1 (K), IC2.2 (OUTPUT), L1.1
NEOPIXEL: FLASH.1 (COM), IC7.IO0, R5.2, RN2.2 (1)
RST: IC7.RST, RESET.1 (COM), RN2.1
RX: IC7.RXD/IO3, PROGRAMMING.2
SCL: IC7.IO5, J2.1, J3.1
SDA: IC7.IO4, J2.2, J3.2
TX: IC7.TXD/IO1, PROGRAMMING.1
VDD: C1.1 (+), C5.1 (+), IC1.1 (VIN), IC2.1 (VIN), J1.PWR, POWER-EXT.1

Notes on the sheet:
qwicc
MCU
Power Supply
Ethernet
I2C
WS2811
Mosfets
Output
Pullups

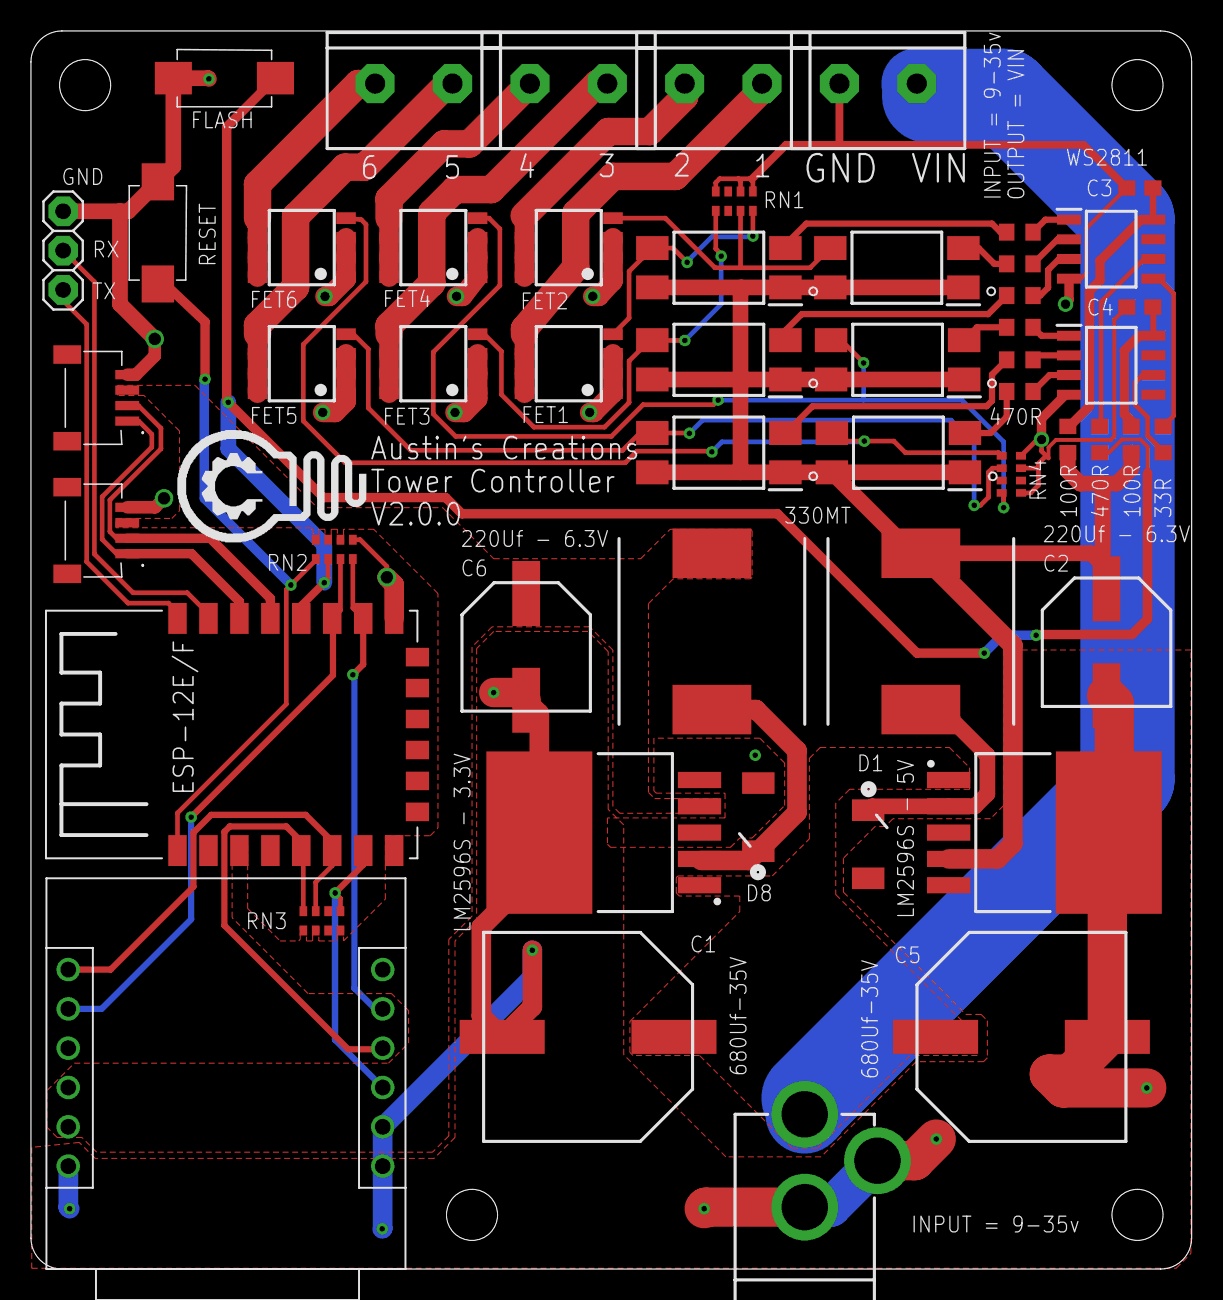
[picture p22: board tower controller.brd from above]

Board: 2 copper layers, 75.0 x 80.0 mm, 53 parts (0 on the bottom side), 46 nets.

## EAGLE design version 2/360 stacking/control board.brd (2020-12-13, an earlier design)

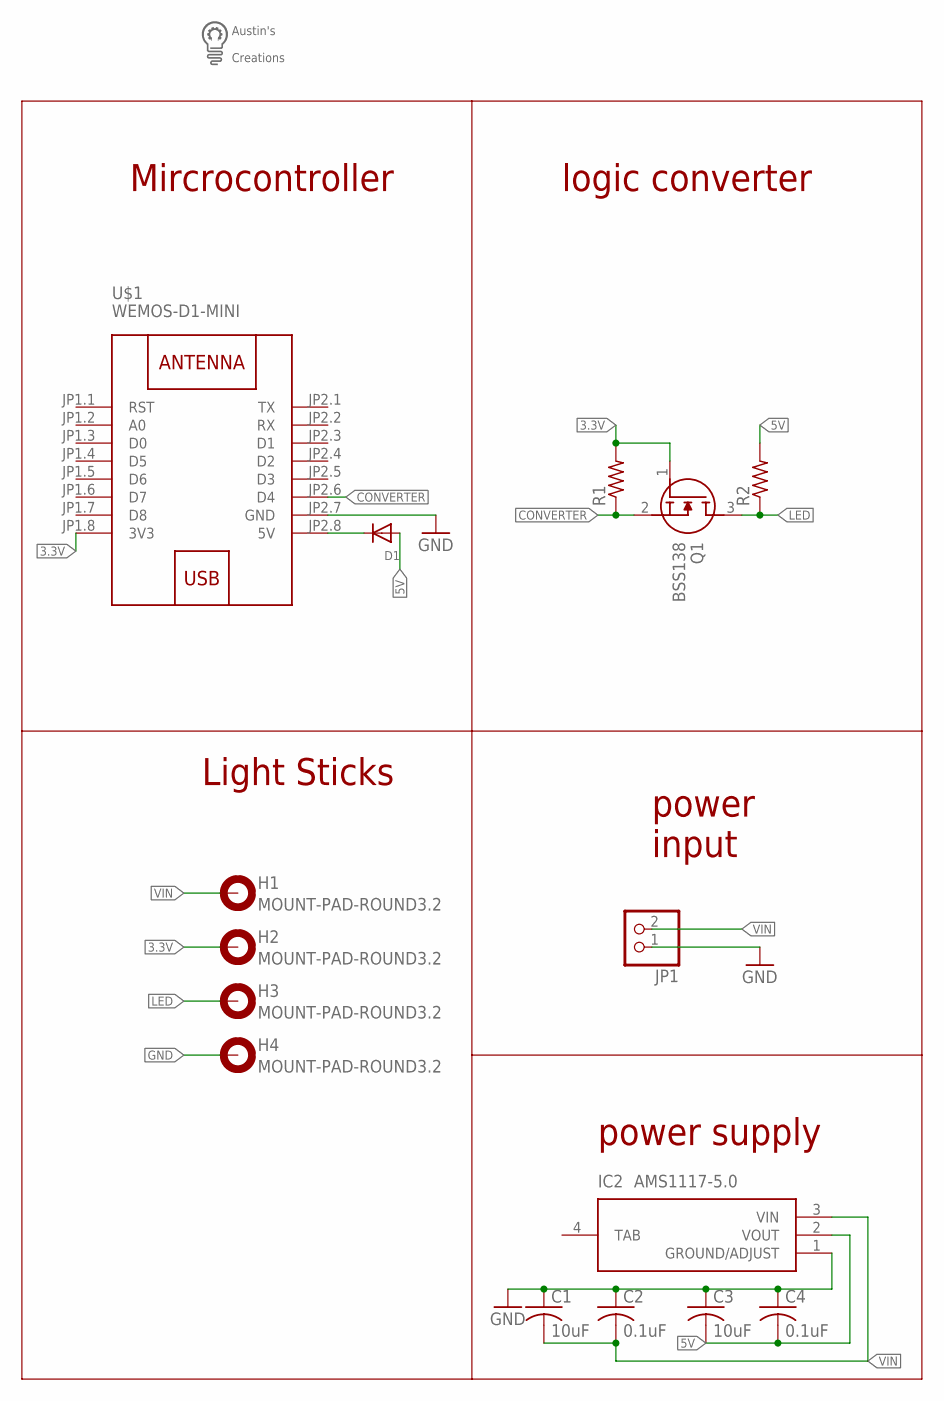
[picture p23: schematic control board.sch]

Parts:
C1, C3: 10uF; C0603
C2, C4: 0.1uF; C0603
D1: DIODESOD-123; SOD-123
H1, H2, H3, H4: MOUNT-PAD-ROUND3.2; 3,2-PAD
IC2: AMS1117-5.0; SOT229P700X180-4N
JP1: PINHD-1X2; 1X02
Q1: BSS138; SOT95P240X120-3N
R1, R2: R-US_R0603; R0603
U$1: WEMOS-D1-MINI
U$2: LOGO

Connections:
3.3V: H2.B3,2, Q1.1 (G), R1.2, U$1.JP1.8 (3V3)
5V: C3.2, C4.2, D1.A, IC2.2 (VOUT), R2.2
CONVERTER: Q1.2 (S), R1.1, U$1.JP2.6 (D4)
GND: C1.1, C2.1, C3.1, C4.1, H4.B3,2, IC2.1 (GROUND/ADJUST), JP1.1, U$1.JP2.7 (GND)
LED: H3.B3,2, Q1.3 (D), R2.1
unnamed: D1.C, U$1.JP2.8 (5V)
VIN: C1.2, C2.2, H1.B3,2, IC2.3 (VIN), JP1.2

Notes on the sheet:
Light Sticks
power supply
power input
Mircrocontroller
logic converter

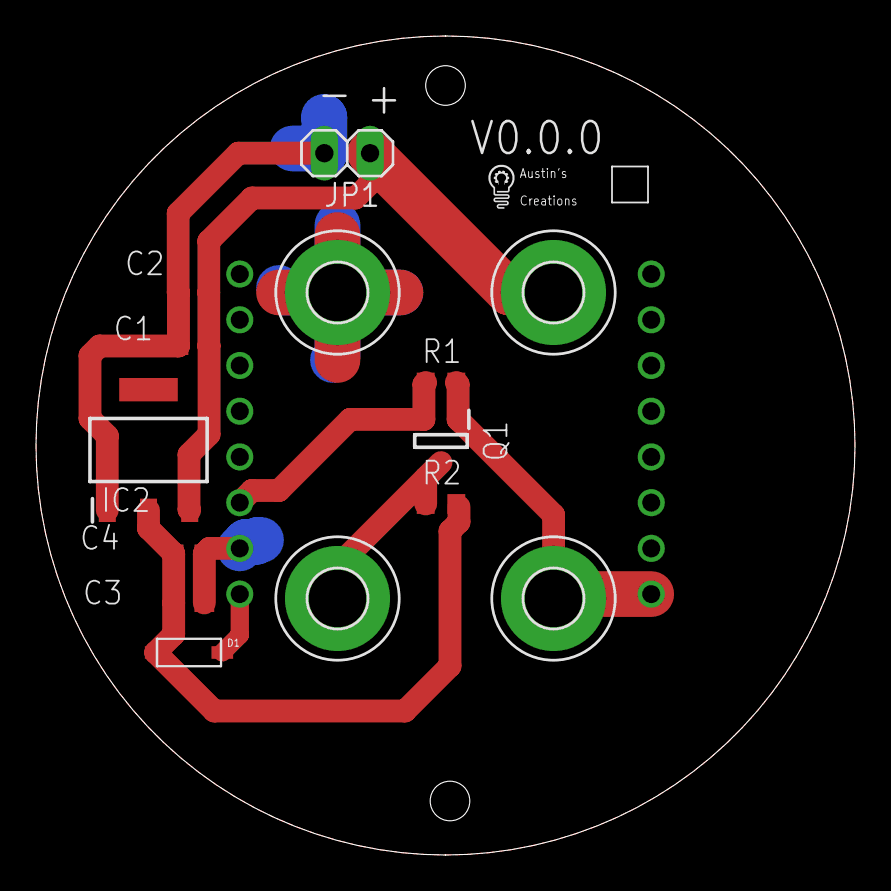
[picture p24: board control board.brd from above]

Board: 2 copper layers, 45.5 x 45.5 mm, 16 parts (1 on the bottom side), 7 nets.

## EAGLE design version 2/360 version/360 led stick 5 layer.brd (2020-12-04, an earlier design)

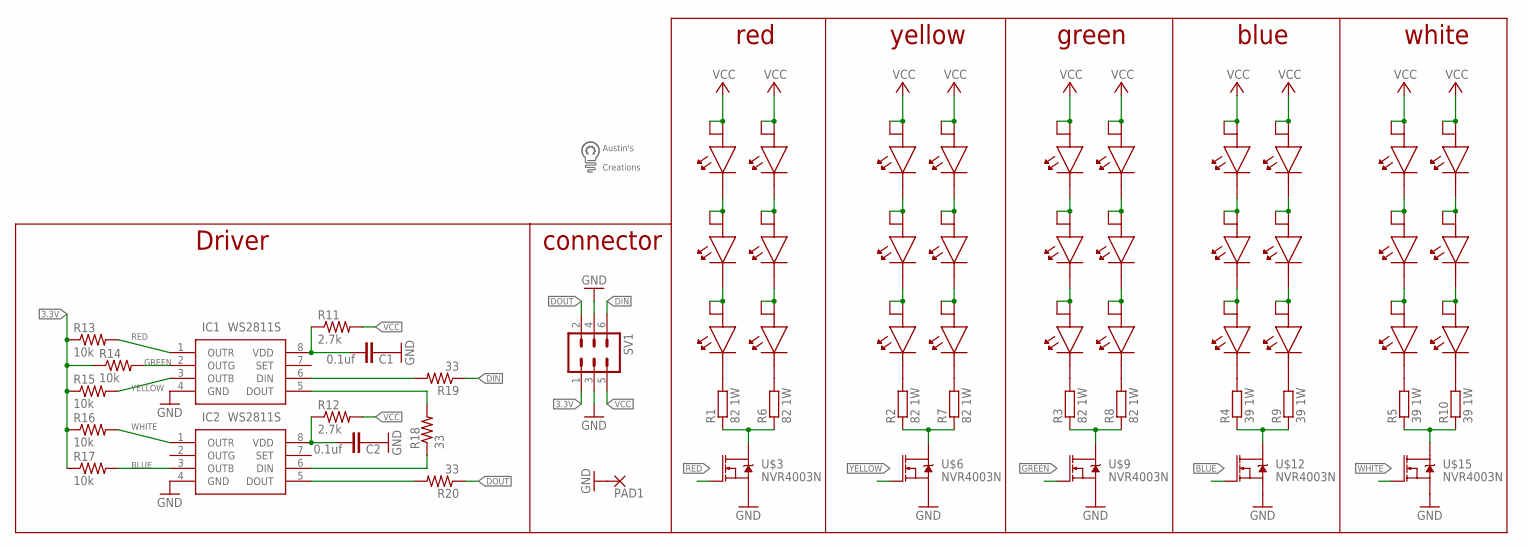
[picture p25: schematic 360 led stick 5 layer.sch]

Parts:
C1, C2: 0.1uf; C0603K
IC1, IC2: WS2811S; SOIC127P600X175-8N
PAD1: WIREPADSMD1,27-254; SMD1,27-2,54
R1, R2, R3, R6, R7, R8: 82 1W; R1210
R4, R5, R9, R10: 39 1W; R1210
R11, R12: 2.7k; R0603
R13, R14, R15, R16, R17: 10k; R0603
R18, R19, R20: 33; R0603
SV1: MA03-2
U$1, U$2, U$4, U$5, U$7, U$8, U$10, U$11, U$13, U$14, U$16, U$17, U$18, U$19, U$20, U$22, U$23, U$24, U$25, U$26, U$27, U$28, U$29, U$30, U$31, U$32, U$33, U$34, U$35, U$36: 5730LED
U$3, U$6, U$9, U$12, U$15: NVR4003N; SOT23
U$21: LOGO

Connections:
3.3V: R13.1, R14.1, R15.1, R16.1, R17.1, SV1.1
BLUE: IC2.3 (OUTB), R17.2, U$12.2 (G)
DIN: R19.1, SV1.6
DOUT: R20.1, SV1.2
GND: C1.1, C2.1, IC1.4 (GND), IC2.4 (GND), PAD1.1, SV1.3, SV1.4, U$3.3 (S), U$6.3 (S), U$9.3 (S), U$12.3 (S), U$15.3 (S)
GREEN: IC1.2 (OUTG), R14.2, U$9.2 (G)
unnamed: U$1.P$2, U$2.P$1, U$2.P$3
unnamed: U$2.P$2, U$4.P$1, U$4.P$3
unnamed: R1.2, U$4.P$2
unnamed: U$5.P$2, U$7.P$1, U$7.P$3
unnamed: U$7.P$2, U$8.P$1, U$8.P$3
unnamed: R2.2, U$8.P$2
unnamed: U$10.P$2, U$11.P$1, U$11.P$3
unnamed: U$11.P$2, U$13.P$1, U$13.P$3
unnamed: R3.2, U$13.P$2
unnamed: U$14.P$2, U$16.P$1, U$16.P$3
unnamed: U$16.P$2, U$17.P$1, U$17.P$3
unnamed: R4.2, U$17.P$2
unnamed: U$18.P$2, U$19.P$1, U$19.P$3
unnamed: U$19.P$2, U$20.P$1, U$20.P$3
unnamed: R5.2, U$20.P$2
unnamed: R1.1, R6.1, U$3.1 (D)
unnamed: R2.1, R7.1, U$6.1 (D)
unnamed: R3.1, R8.1, U$9.1 (D)
unnamed: R4.1, R9.1, U$12.1 (D)
unnamed: R5.1, R10.1, U$15.1 (D)
unnamed: U$22.P$2, U$23.P$1, U$23.P$3
unnamed: U$23.P$2, U$24.P$1, U$24.P$3
unnamed: R6.2, U$24.P$2
unnamed: U$25.P$2, U$26.P$1, U$26.P$3
unnamed: U$26.P$2, U$27.P$1, U$27.P$3
unnamed: R7.2, U$27.P$2
unnamed: U$28.P$2, U$29.P$1, U$29.P$3
unnamed: U$29.P$2, U$30.P$1, U$30.P$3
unnamed: R8.2, U$30.P$2
unnamed: U$31.P$2, U$32.P$1, U$32.P$3
unnamed: U$32.P$2, U$33.P$1, U$33.P$3
unnamed: R9.2, U$33.P$2
unnamed: U$34.P$2, U$35.P$1, U$35.P$3
unnamed: U$35.P$2, U$36.P$1, U$36.P$3
unnamed: R10.2, U$36.P$2
unnamed: C1.2, IC1.8 (VDD), R11.1
unnamed: IC1.6 (DIN), R19.2
unnamed: IC2.6 (DIN), R18.1
unnamed: C2.2, IC2.8 (VDD), R12.1
unnamed: IC1.5 (DOUT), R18.2
unnamed: IC2.5 (DOUT), R20.2
RED: IC1.1 (OUTR), R13.2, U$3.2 (G)
VCC: R11.2, R12.2, SV1.5, U$1.P$1, U$1.P$3, U$5.P$1, U$5.P$3, U$10.P$1, U$10.P$3, U$14.P$1, U$14.P$3, U$18.P$1, U$18.P$3, U$22.P$1, U$22.P$3, U$25.P$1, U$25.P$3, U$28.P$1, U$28.P$3, U$31.P$1, U$31.P$3, U$34.P$1, U$34.P$3
WHITE: IC2.1 (OUTR), R16.2, U$15.2 (G)
YELLOW: IC1.3 (OUTB), R15.2, U$6.2 (G)

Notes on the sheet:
red
yellow
green
blue
white
connector
Driver

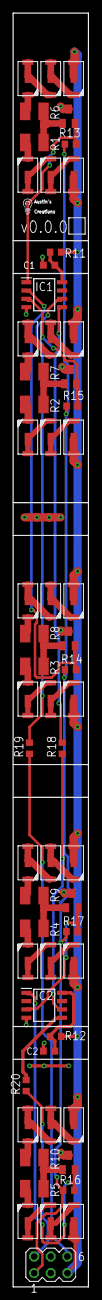
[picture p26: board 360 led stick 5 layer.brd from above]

Board: 2 copper layers, 11.5 x 194.5 mm, 62 parts (1 on the bottom side), 51 nets.

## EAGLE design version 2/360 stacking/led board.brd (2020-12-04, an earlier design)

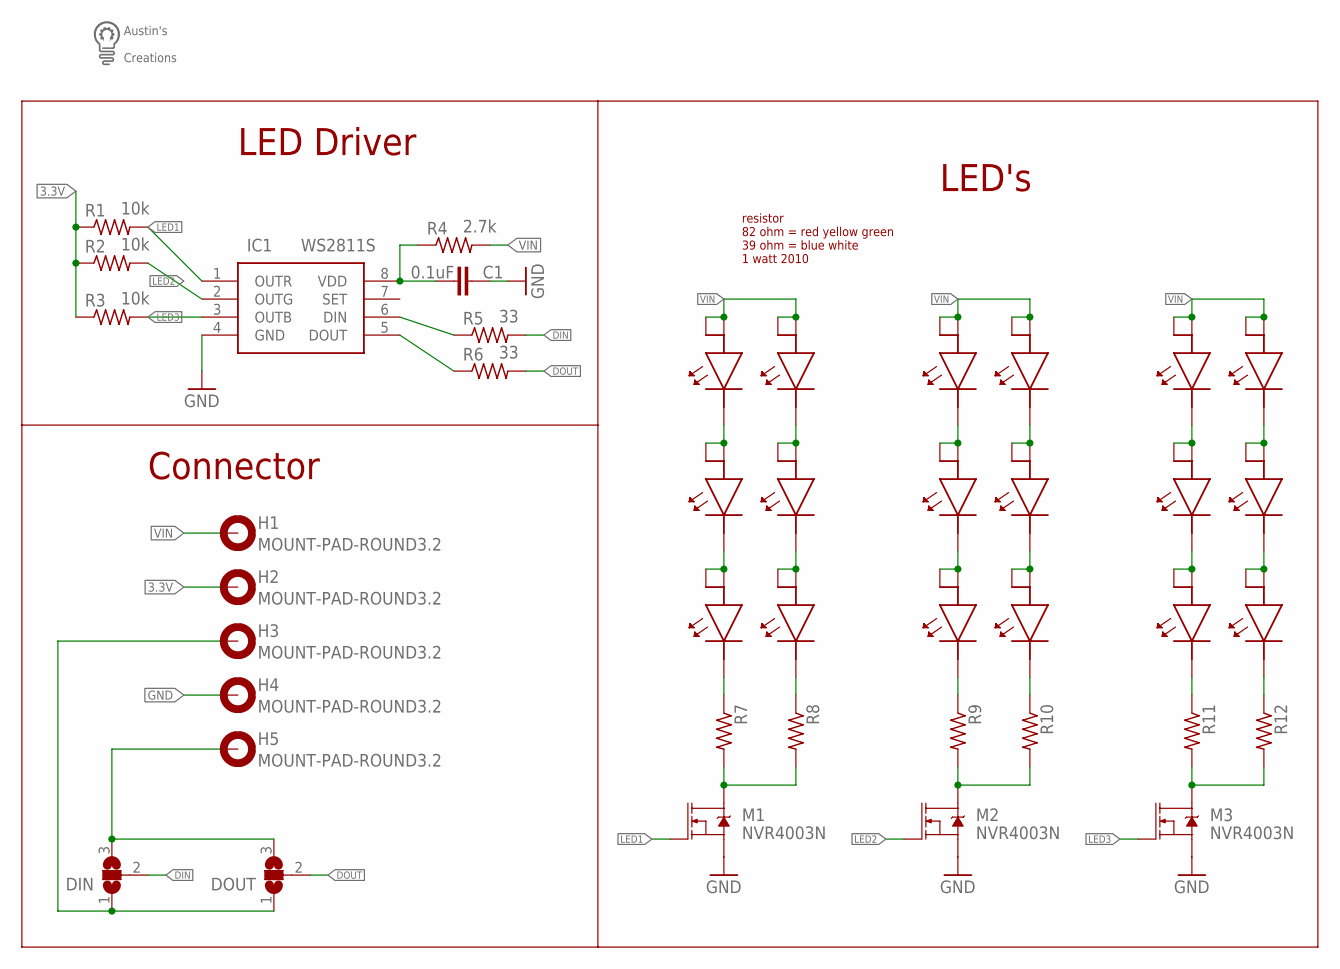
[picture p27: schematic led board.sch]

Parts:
C1: 0.1uF; C0603K
DIN: SJ2WW; SJ_2W
DOUT: SJ2WW; SJ_2W
H1, H2, H3, H4, H5: MOUNT-PAD-ROUND3.2; 3,2-PAD
IC1: WS2811S; SOIC127P600X175-8N
L1, L2, L3, L4, L5, L6, L7, L8, L9, L10, L11, L12, L13, L14, L15, L16, L17, L18: 5730LED
M1, M2, M3: NVR4003N; SOT23
R1, R2, R3: 10k; R0603
R4: 2.7k; R0603
R5, R6: 33; R0603
R7, R8, R9, R10, R11, R12: R-US_R2010; R2010
U$2: LOGO

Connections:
3.3V: H2.B3,2, R1.1, R2.1, R3.1
DIN: DIN.2, R5.2
DOUT: DOUT.2, R6.2
GND: C1.1, H4.B3,2, IC1.4 (GND), M1.3 (S), M2.3 (S), M3.3 (S)
LED1: IC1.1 (OUTR), M1.2 (G), R1.2
LED2: IC1.2 (OUTG), M2.2 (G), R2.2
LED3: IC1.3 (OUTB), M3.2 (G), R3.2
unnamed: DIN.3, DOUT.3, H5.B3,2
unnamed: DIN.1, DOUT.1, H3.B3,2
unnamed: L3.P$2, R7.1
unnamed: C1.2, IC1.8 (VDD), R4.1
unnamed: IC1.6 (DIN), R5.1
unnamed: IC1.5 (DOUT), R6.1
unnamed: L2.P$2, L3.P$1, L3.P$3
unnamed: L1.P$2, L2.P$1, L2.P$3
unnamed: M1.1 (D), R7.2, R8.2
unnamed: L6.P$2, R8.1
unnamed: L5.P$2, L6.P$1, L6.P$3
unnamed: L4.P$2, L5.P$1, L5.P$3
unnamed: L9.P$2, R9.1
unnamed: L8.P$2, L9.P$1, L9.P$3
unnamed: L7.P$2, L8.P$1, L8.P$3
unnamed: M2.1 (D), R9.2, R10.2
unnamed: L12.P$2, R10.1
unnamed: L11.P$2, L12.P$1, L12.P$3
unnamed: L10.P$2, L11.P$1, L11.P$3
unnamed: L15.P$2, R11.1
unnamed: L14.P$2, L15.P$1, L15.P$3
unnamed: L13.P$2, L14.P$1, L14.P$3
unnamed: M3.1 (D), R11.2, R12.2
unnamed: L18.P$2, R12.1
unnamed: L17.P$2, L18.P$1, L18.P$3
unnamed: L16.P$2, L17.P$1, L17.P$3
VIN: H1.B3,2, L1.P$1, L1.P$3, L4.P$1, L4.P$3, L7.P$1, L7.P$3, L10.P$1, L10.P$3, L13.P$1, L13.P$3, L16.P$1, L16.P$3, R4.2

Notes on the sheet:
Connector
resistor 82 ohm = red yellow green 39 ohm = blue white 1 watt 2010
LED Driver
LED's



Board: 2 copper layers, 45.5 x 45.5 mm, 43 parts (15 on the bottom side), 34 nets.

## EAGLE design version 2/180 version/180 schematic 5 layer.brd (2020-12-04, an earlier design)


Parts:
C1, C3: 10uF; C0603
C2, C4: 0.1uF; C0603
D1: DIODESOD-123; SOD-123
IC2: AMS1117-5.0; SOT229P700X180-4N
JP1: PINHD-1X2; 1X02
R1, R2, R3, R6, R7, R8: 82 1W; R2010
R4, R5, R9, R10: 39 1W; R2010
U$1, U$2, U$3, U$4, U$5: NVR4003N; SOT23
U$6, U$7, U$8, U$9, U$10, U$11, U$12, U$13, U$14, U$15, U$16, U$17, U$18, U$19, U$20, U$23, U$24, U$25, U$26, U$27, U$28, U$29, U$30, U$31, U$32, U$33, U$34, U$35, U$36, U$37: 5730LED
U$21: WEMOS-D1-MINI
U$22: LOGO

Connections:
3.3: U$21.JP1.8 (3V3)
5V: C3.2, C4.2, D1.A, IC2.2 (VOUT)
A0: U$21.JP1.2 (A0)
BLUE: U$4.2 (G), U$21.JP2.5 (D3)
D0: U$21.JP1.3 (D0)
D6: U$21.JP1.5 (D6)
D7: U$21.JP1.6 (D7)
D8: U$21.JP1.7 (D8)
GND: C1.1, C2.1, C3.1, C4.1, IC2.1 (GROUND/ADJUST), JP1.1, U$1.3 (S), U$2.3 (S), U$3.3 (S), U$4.3 (S), U$5.3 (S), U$21.JP2.7 (GND)
GREEN: U$3.2 (G), U$21.JP2.2 (RX)
unnamed: D1.C, U$21.JP2.8 (5V)
unnamed: U$6.P$2, U$7.P$1, U$7.P$3
unnamed: U$9.P$2, U$10.P$1, U$10.P$3
unnamed: R1.1, R6.1, U$1.1 (D)
unnamed: R2.1, R7.1, U$2.1 (D)
unnamed: U$12.P$2, U$13.P$1, U$13.P$3
unnamed: U$15.P$2, U$16.P$1, U$16.P$3
unnamed: U$18.P$2, U$19.P$1, U$19.P$3
unnamed: U$7.P$2, U$8.P$1, U$8.P$3
unnamed: R1.2, U$8.P$2
unnamed: R2.2, U$11.P$2
unnamed: R3.2, U$14.P$2
unnamed: R4.2, U$17.P$2
unnamed: R5.2, U$20.P$2
unnamed: U$19.P$2, U$20.P$1, U$20.P$3
unnamed: U$16.P$2, U$17.P$1, U$17.P$3
unnamed: U$13.P$2, U$14.P$1, U$14.P$3
unnamed: U$10.P$2, U$11.P$1, U$11.P$3
unnamed: U$23.P$2, U$24.P$1, U$24.P$3
unnamed: U$24.P$2, U$25.P$1, U$25.P$3
unnamed: R3.1, R8.1, U$3.1 (D)
unnamed: R4.1, R9.1, U$4.1 (D)
unnamed: R5.1, R10.1, U$5.1 (D)
unnamed: R6.2, U$25.P$2
unnamed: U$29.P$2, U$30.P$1, U$30.P$3
unnamed: U$26.P$2, U$27.P$1, U$27.P$3
unnamed: R7.2, U$28.P$2
unnamed: U$27.P$2, U$28.P$1, U$28.P$3
unnamed: R8.2, U$31.P$2
unnamed: U$30.P$2, U$31.P$1, U$31.P$3
unnamed: U$32.P$2, U$33.P$1, U$33.P$3
unnamed: R9.2, U$34.P$2
unnamed: U$33.P$2, U$34.P$1, U$34.P$3
unnamed: U$35.P$2, U$36.P$1, U$36.P$3
unnamed: R10.2, U$37.P$2
unnamed: U$36.P$2, U$37.P$1, U$37.P$3
RED: U$1.2 (G), U$21.JP1.4 (D5)
RST: U$21.JP1.1 (RST)
SCL: U$21.JP2.3 (D1)
SDA: U$21.JP2.4 (D2)
VIN: C1.2, C2.2, IC2.3 (VIN), JP1.2, U$6.P$1, U$6.P$3, U$9.P$1, U$9.P$3, U$12.P$1, U$12.P$3, U$15.P$1, U$15.P$3, U$18.P$1, U$18.P$3, U$23.P$1, U$23.P$3, U$26.P$1, U$26.P$3, U$29.P$1, U$29.P$3, U$32.P$1, U$32.P$3, U$35.P$1, U$35.P$3
WHITE: U$5.2 (G), U$21.JP2.6 (D4)
YELLOW: U$2.2 (G), U$21.JP2.1 (TX)

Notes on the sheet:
red
yellow
green
blue
white



Board: 2 copper layers, 41.5 x 194.5 mm, 54 parts (2 on the bottom side), 44 nets.

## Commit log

2022-02-05 fitment clearance around ethernet jack
    [main lid.stl]
2022-02-06 updating height to better fit sensors
    [sensor lid.stl]
2022-12-27 add latest version
    [tower controler v2.kicad_pcb, tower controler v2.kicad_sch]

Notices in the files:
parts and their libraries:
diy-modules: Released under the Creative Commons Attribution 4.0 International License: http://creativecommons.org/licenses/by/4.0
